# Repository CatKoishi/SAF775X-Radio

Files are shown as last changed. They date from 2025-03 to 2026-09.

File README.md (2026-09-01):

<!-- markdownlint-disable MD026 MD028 MD033 MD041 -->

<div align="center">
  <a href="https://github.com/CatKoishi" target="_blank">
    
  </a>

<h1><ruby>SAF775X Radio<rp>(</rp><rt>DIRANA3 收音机</rt><rp>)</ruby></h1>

</div>

主图 收音机实物图

## 📖 简介

基于恩智浦 Dirana3 系列的多波段收音机，具体型号为 SAF775X，支持双天线接收，可启用多种高级收音算法，由于使用的是演示密钥，所以开机3小时后会自动复位

此密钥不涉及对 SAF775X 芯片的破解，没有商用价值，与 NXP 的企业权益无冲突，演示密钥与部分程序来源于[rayc345/WTCRC775X](https://github.com/rayc345/WTCRC775X)

#### 🔗 项目链接

 ➡️ [软件开源 GitHub](https://github.com/CatKoishi/SAF775X-Radio)

 ➡️ [硬件开源 OSHWHub](https://oshwhub.com/imhhh/saf775x-radio)

## 📦 功能

略，请看视频（没录）

## 📦 ToDo

- [ ] 收音动态高切调节
- [ ] 音频静态/动态响度
- [ ] 音频正弦波/噪声发生器UI
- [ ] ALE 自动响度均衡
- [x] UltraBass 自适应虚拟低音
- [ ] 音频滤波器组驱动与UI
- [x] 扬声器启用自动单声道
- [ ] 主界面EQ/Tone
- [ ] 低功耗与关机
- [ ] 针对AM噪声的pEQ
- [ ] 利用通用滤波器，延迟线的伪立体声

## 固件下载/更新

### 下载

方法 1:

- 将收音机通过 USB 连接到电脑（需安装CH340驱动）
- 打开收音机电源开关到耳机方向
- **保持短接** "J401" 的同时短按复位键
- 通过 `GD32 All In One Programmer`（GD官网提供）使用串口下载

方法 2:

- 使用调试器（DAP-Link，GD-Link等）下载

### 更新

- 将收音机通过 USB 连接到电脑（需安装CH340驱动）
- 进入菜单，导航到 `Device`-`Firmware Update` 按下 OK 键
- 长按 OK 键直到屏幕内容消失
- 通过 `GD32 All In One Programmer`（GD官网提供）使用串口下载

---

### Download

Method 1: 

- Connect the radio to your PC with functional USB cable(CH340 Driver Required)
- Turn on the power switch
- **Keep** Jumper "J401" shorted and press RST button
- Use `GD32 All In One Programmer`(Provided by GigaDevice) to download

Method 2:

- Use Debugger(DAP-Link, GD-Link, etc.) to download directly

### Update

- Connect the radio to your PC with functional USB cable(CH340 Driver Required)
- Navigate to `Device`-`Firmware Update` and press OK button
- Long press OK button and wait for screen turn off
- Use `GD32 All In One Programmer`(Provided by GigaDevice) to download

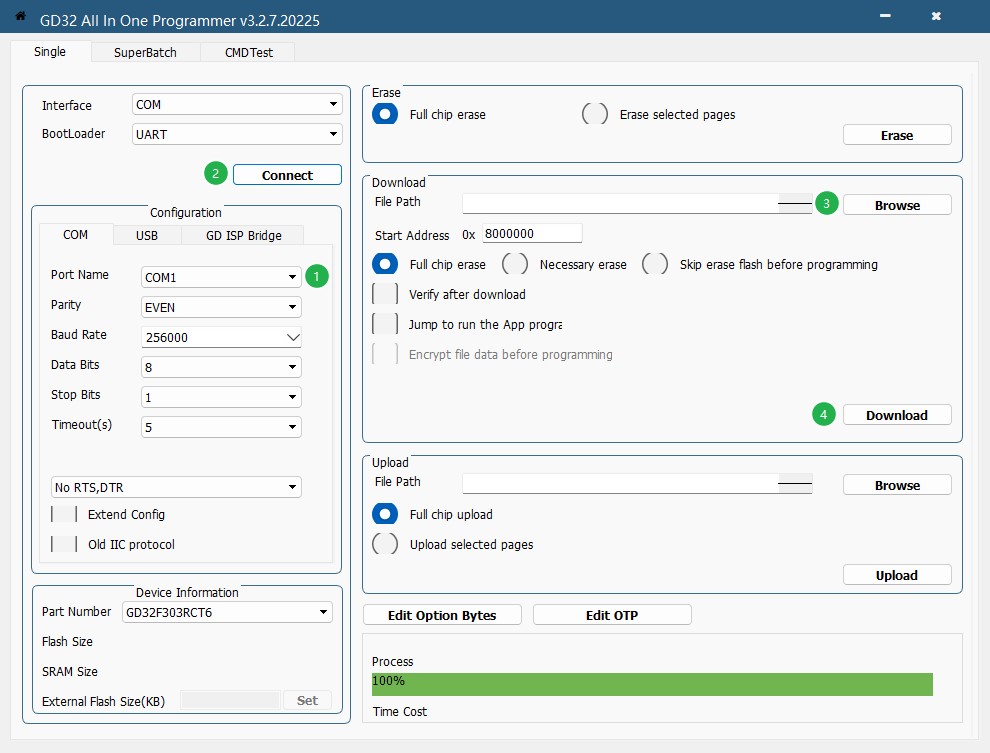
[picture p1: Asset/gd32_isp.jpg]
ISP GD32 All In One Programmer流程


---

## 📝 更新记录

### 20260831-2.10

- 增加音频采样率切换

### 20260829-2.9

- 优化菜单位置
- 支持交换左右编码器功能

### 20260605-2.8.1

- 修复多处无关设置
- 修复结构体更新后 flash 没有同步更新的问题
- 更新 README 固件下载/更新方法
### 20260831-2.9

- 增加 44.1 kHz 与 48 kHz 采样率切换

### 20260527-2.8

- 新增 Coax Output 与 Host I2S0 Out 开关
- 启用 Coax Output 或 Host I2S0 Out 时自动关闭 AMP 电源，避免喇叭继续输出
- 优化同轴/Host I2S0 输出切换时的喇叭输出控制
- 调整存台上限：LW 20 台，MW 50 台，FM 150 台，SW 200 台
- 修复 100 台以上存台时的索引与主界面显示问题
- 修复 ATS Threshold 设置无法保存的问题

### 20260519-2.7

- 增加电台删除功能 [设置-Search-Manage Memory]

### 20260417-2.6

- 修复错误的 SFUD 擦除参数
- CRC 相同的实时信息不会写入 Flash

### 20260101-2.5

- 修复设置保存在某些情况下的错误
- 修复错误的静音设置
- 修复启动过程中某些配置未设置

### 20251121-2.4

- 将 FlashDB 更换为 LittleFS, 理论上储存更加稳健

### 20250707-2.3.1

- 开机按住左编码器会强制初始化设置
- 限制对比度调节范围

### 20250408-2.3

- Flash 驱动改为 SFUD，理论上兼容所有支持 JEDEC 标准的 Flash (容量 > 2MByte)
- 修复某些情况下 Device 下的设置不保存的问题

### 20250321-2.2.1

- 设置版本不匹配时重置数据库，减小报错

### 20250320-2.2

- 增加 RDS RadioText 显示
- 非 EmiFree 模式下存台信息由 CH.05 改为 CH.05/14
- 将存台序号最小值改为 01
- 修复在非 EmiFree 模式下 RDS PI 码侵占存台序号的问题
- 修复进退菜单后主界面的 RDS PI/PS 信息丢失
- 修复错误读取版本信息

### 20250311-2.1

- FMSI 立体声等级可调
- 使用扬声器时可设置自动输出单声道（提高信噪比）

### 20250308-2.0

- FM切换频率无静音
- 所有设置使用FlashDB存储，支持Flash磨损均衡
- 无操作1分钟后存储实时信息
- 增加主菜单图标

<details>
<summary>历史记录（点击展开）</summary>

### 20240802-1.7a

- 超频SPI通讯速率到30MH

### 20240801-1.7

- 重构主界面UI
- 新增Audio目录图标
- 新增RDS PI PS信息展示

### 20240723-1.6

- 重构LCD DMA刷屏函数与GUI函数，减小屏幕通信干扰
- 修复开机屏幕不打开无限背光的Bug

### 20231105-1.5

- 增加DAC音频增益3dB
- 略微降低屏幕通信干扰
- VU表自衰减

### 20231007-1.4

- 新增About图标

### 20230924(ER)

- 修复flash排列错误

### 20230921-1.4

- 修复开机LNA不启用的Bug
- 时钟源更改为内部RC振荡器
- 版本标记修改
- 增加UltraBass功能（KeyCode）
- 增加GSA，VU流畅度

### 20230913-1.3

- 修复切换波段静音解除的问题
- 修复775x复位后静音解除的问题
- 增加NoiseBlanker, SoftMute设置
- 设置带宽增加指示

### 20230912-1.2

- 修改音量线性度
- 修改音量步进
- 优化GSA,VU,RSSI延迟
- 加快VU表衰落速度

### 20230911-1.1

- 降低屏幕通信干扰

</details>

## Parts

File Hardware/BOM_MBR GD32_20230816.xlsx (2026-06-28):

主板
No. | Quantity | Comment | Designator | Footprint | Value | Manufacturer Part | Manufacturer | Supplier Part | Supplier | Device
1 | 3 | PH-2AW | BAT1,SPK1,SPK2 | CONN-TH_2P-P2.00_PH-2AW |  | PH-2AW | BOOMELE(博穆精密) | C16965 | LCSC | PH-2AW_C16965
2 | 2 | 6.8n | C1,C2 | C0603_S | 6.8n |  |  |  |  | CAP_0603
3 | 2 | 47n | C3,C5 | C0603 | 47n |  |  |  |  | CAP_0603
4 | 1 | 62p | C4 | C0603 | 62p |  |  |  |  | CAP_0603
5 | 6 | 22u | C101,C102,C104,C105,C427,C430 | C0805 | 22u |  |  |  |  | CAP_0805
6 | 15 | 1u | C107,C108,C111,C112,C213,C220,C228,C249,C254,C262,C266,C303,C304,C409,C424 | C0603_S | 1u |  |  |  |  | CAP_0603
7 | 18 | 10u | C109,C110,C113,C114,C115,C118,C119,C120,C121,C128,C129,C133,C201,C401,C404,C425,C429,C431 | C0603_S | 10u |  |  |  |  | CAP_0603
8 | 8 | 1n | C117,C205,C207,C209,C232,C234,C251,C252 | C0603_S | 1n |  |  |  |  | CAP_0603
9 | 2 | 100u | C122,C131 | CAP-SMD_L3.5-W2.8 | 100u | TAJB107K006RNJ | Kyocera AVX | C16133 | LCSC | TAJB107K006RNJ
10 | 39 | 100n | C123,C124,C132,C202,C203,C204,C206,C208,C210,C211,C212,C217,C218,C219,C221,C240,C246,C247,C250,C255,C263,C264,C265,C267,C305,C307,C313,C320,C325,C402,C403,C405,C406,C407,C408,C411,C415,C421,C428 | C0603_S | 100n |  |  |  |  | CAP_0603
11 | 1 | 220u | C126 | CAP-TH_BD6.3-P2.50-D1.0-FD | 220u | SPZ1AM221E05O00R | AISHI(艾华集团) |  | LCSC | SPZ1AM221E05O00R
12 | 4 | 4.7u | C130,C231,C321,C326 | C0603_S | 4.7u |  |  |  |  | CAP_0603
13 | 6 | 12p | C222,C223,C422,C423,C436,C437 | C0603_S | 12p |  |  |  |  | CAP_0603
14 | 3 | 470n | C224,C301,C314 | C0603_S | 470n |  |  |  |  | CAP_0603
15 | 2 | 3.3n | C225,C245 | C0603_S | 3.3n |  |  |  |  | CAP_0603
16 | 7 | 10n | C226,C227,C410,C417,C418,C419,C420 | C0603_S | 10n |  |  |  |  | CAP_0603
17 | 2 | 1.5p | C229,C241 | C0603_S | 1.5p |  |  |  |  | CAP_0603
18 | 1 | 2.2n | C230 | C0603_S | 2.2n |  |  |  |  | CAP_0603
19 | 1 | 1p | C233 | C0603_S | 1p |  |  |  |  | CAP_0603
20 | 1 | 10p | C235 | C0603_S | 10p |  |  |  |  | CAP_0603
21 | 1 | 6p | C236 | C0603_S | 6p |  |  |  |  | CAP_0603
22 | 1 | 8p | C237 | C0603_S | 8p |  |  |  |  | CAP_0603
23 | 2 | 47n | C238,C239 | C0603_S | 47n |  |  |  |  | CAP_0603
24 | 1 | 470p | C242 | C0603_S | 470p |  |  |  |  | CAP_0603
25 | 1 | 15p | C243 | C0603_S | 15p |  |  |  |  | CAP_0603
26 | 2 | 330p | C244,C253 | C0603_S | 330p |  |  |  |  | CAP_0603
27 | 1 | 220n | C248 | C0603_S | 220n |  |  |  |  | CAP_0603
28 | 3 | 22u | C302,C318,C324 | CAP-SMD_L3.2-W1.6 | 22u | CA45-A-16V-22uF-K | CEC(振华新云) |  | LCSC | CA45-A-16V-22uF-K
29 | 4 | 2.2u | C309,C312,C317,C323 | C0603_S | 2.2u |  |  |  |  | CAP_0603
30 | 2 | 56p | C433,C434 | C0603 | 56p |  |  |  |  | CAP_0603
31 | 1 | 20p | C435 | C0603 | 20p |  |  |  |  | CAP_0603
32 | 1 | PJ-3062-HD-G | CN1 | AUDIO-TH_PJ-3062-HD-G |  | PJ-3062-HD-G | XKB Connectivity(中国星坤) | C431042 | LCSC | PJ-3062-HD-G
33 | 1 | SMF6.0CA | D101 | SOD-123FL_L2.8-W1.8-LS3.7-BI |  | SMF6.0CA | Slkor(萨科微) | C920180 | LCSC | SMF6.0CA_C920180
34 | 1 | S3MB | D102 | SMB_L4.6-W3.6-LS5.3-RD |  | S3MB | MDD | C47524 | LCSC | S3MB_C47524
35 | 2 | bf563e83ec7f4ca1b05c8bcd0d4c01ab | D201,D202 | SOD523 |  |  |  |  |  | BA891
36 | 1 | SD103AWS | D403 | SOD-323_L1.8-W1.3-LS2.5-RD |  | SD103AWS | Hottech(合科泰) | C181207 | LCSC | SD103AWS
37 | 2 | CBW322513U221T | FB1,FB2 | IND-SMD_L3.2-W2.5_L3225 |  | CBW322513U221T | FH(风华) | C394512 | LCSC | CBW322513U221T
38 | 1 | AFA01-S16FCA-00 | FPC403 | FPC-SMD_P1.00-16P_FGS-XJ-H2.0 |  | AFA01-S16FCA-00 | JS(钜硕电子) | C262758 | LCSC | AFA01-S16FCA-00
39 | 2 | HDR-M_2.54_1x2P | J401,MW_ANT1 | HDR-TH_2P-P2.54-V-M-1 |  |  |  | C124375 |  | HDR-M_2.54_1x2P
40 | 2 | 150nH | L1,L4 | L0603 | 150nH |  |  |  |  | L_0603
41 | 2 | 82nH | L2,L3 | L0603 | 82nH |  |  |  |  | L_0603
42 | 1 | 51nH | L6 | L0603 | 51nH |  |  |  |  | L_0603
43 | 1 | 2.2uH | L101 | IND-SMD_L7.4-W6.6_1 |  | MS0630-2R2M | COILMX | C380175 | LCSC | 2.2uH
44 | 6 | BLM18AG601SN1D | L201,L202,L203,L206,L212,L401 | L0603 |  | BLM18AG601SN1D | muRata(村田) | C19330 | LCSC | BLM18AG601SN1D
45 | 2 | 47uH | L204,L205 | L1210 | 47uH | LQH32MN470J23L | muRata(村田) | C113077 | LCSC | LQH32MN470J23L
46 | 1 | 880nH | L207 | L1206 | 880nH | LQH31HNR88J03L | muRata(村田) | C417125 | LCSC | LQH31HNR88J03L
47 | 1 | 3.3uH | L208 | IND-SMD_L2.9-W2.5 | 3.3uH | AISC-1008F-3R3G-T | ABRACON | C187024 | LCSC | AISC-1008F-3R3G-T
48 | 1 | 290nH | L209 | L1206 | 290nH | LQH31HNR29K03L | muRata(村田) | C337900 | LCSC | LQH31HNR29K03L
49 | 1 | 270nH | L210 | IND-SMD_L2.9-W2.8 | 270nH | AISC-1008-R27G-T | ABRACON | C186997 | LCSC | AISC-1008-R27G-T
50 | 1 | 2.2uH | L402 | IND-SMD_L2.5-W2.0 | 2.2uH | 252012CDMCDDS-2R2MC | Sumida(胜美达) | C351245 | LCSC | 252012CDMCDDS-2R2MC
51 | 1 | LED-0603_R | LED101 | LED0603_RED |  | 19-217/R6C-AL1M2VY/3T | EVERLIGHT(台湾亿光) | C72044 | LCSC | LED-0603_R_LED0603_RED(1)
52 | 1 | SK-12E12-G5 | PWR_SW1 | SW-TH_SK-12E12-G5 |  | SK-12E12-G5 | 韩国韩荣 | C136720 | LCSC | SK-12E12-G5
53 | 1 | AP60P20Q | Q101 | DFN-8_L3.3-W3.3-P0.65-BL |  | AP60P20Q | ALLPOWER(铨力) | C2828591 | LCSC | AP60P20Q
54 | 2 | WST2333 | Q102,Q105 | SOT-23-3_L2.9-W1.3-P1.90-LS2.4-BR_1 |  | WST2333 | WINSOK微硕 | C377859 | LCSC | WST2333
55 | 2 | WNM2021 | Q103,Q104 | SOT-323-3_L2.0-W1.3-P1.30-LS2.1-BR |  | WNM2021 | TECH PUBLIC(台舟) | C2940608 | LCSC | WNM2021
56 | 1 | BC847B,215 | Q201 | SOT-23-3_L2.9-W1.3-P1.90-LS2.4-BR |  | BC847B,215 | Nexperia(安世) | C57668 | LCSC | BC847B,215
57 | 1 | 0.5 | R101 | R0603 | 0.5 |  |  |  |  | Res_0603
58 | 7 | 51K | R102,R113,R117,R314,R322,R324,R419 | R0603 | 51K |  |  |  |  | Res_0603
59 | 3 | 1K | R103,R104,R121 | R0603 | 1K |  |  |  |  | Res_0603
60 | 2 | 5.1K | R105,R106 | R0603 | 5.1K |  |  |  |  | Res_0603
61 | 14 | 10K | R107,R110,R122,R205,R206,R401,R402,R403,R414,R416,R423,R425,R426,R428 | R0603 | 10K |  |  |  |  | Res_0603
62 | 11 | 100K | R108,R111,R114,R115,R118,R119,R123,R318,R420,R429,R430 | R0603 | 100K |  |  |  |  | Res_0603
63 | 1 | 10 | R109 | R0603 | 10 |  |  |  |  | Res_0603
64 | 2 | 147K | R112,R417 | R0603 | 147K |  |  |  |  | Res_0603
65 | 8 | 21K | R116,R217,R301,R302,R303,R313,R316,R317 | R0603 | 21K |  |  |  |  | Res_0603
66 | 3 | 3.3K | R120,R421,R422 | R0603 | 3.3K |  |  |  |  | Res_0603
67 | 1 | 82 | R201 | R0603 | 82 |  |  |  |  | Res_0603
68 | 1 | NC | R202 | R0603 | NC |  |  |  |  | Res_0603
69 | 2 | 470K | R203,R204 | R0603 | 470K |  |  |  |  | Res_0603
70 | 2 | 22 | R207,R209 | R0603 | 22 |  |  |  |  | Res_0603
71 | 1 | 18 | R208 | R0603 | 18 |  |  |  |  | Res_0603
72 | 4 | 100 | R210,R211,R215,R424 | R0603 | 100 |  |  |  |  | Res_0603
73 | 1 | 820 | R212 | R0603 | 820 |  |  |  |  | Res_0603
74 | 3 | 1M | R213,R214,R415 | R0402 | 1M |  |  |  |  | Res_0402
75 | 1 | 2.2K | R216 | R0603 | 2.2K |  |  |  |  | Res_0603
76 | 2 | U.FL-R-SMT-1(80) | RF201,RF202 | RF-SMD_FRF05002-JSS103M |  | U.FL-R-SMT-1(80) | HRS(广濑) | C88374 | LCSC | U.FL-R-SMT-1(80)_C88374
77 | 4 | 100 | RN401,RN403,RN405,RN406 | RES-ARRAY-SMD_0603-8P-L3.2-W1.6-BL | 100 | RC-ML08W101JT | FH(风华) | C79203 | LCSC | RC-ML08W101JT
78 | 1 | TS342A2P-WZ | RST1 | SW-SMD_L4.0-W2.9-LS5.0 |  | TS342A2P-WZ | SHOU HAN(首韩) | C557591 | LCSC | TS342A2P-WZ
79 | 1 | HDR-M_2.54_1x3P | SWD1 | HDR-TH_3P-P2.54-V-M |  |  |  | C2937625 |  | HDR-M_2.54_1x3P
80 | 1 | A1313AN-0001GGH=P3 | T201 | 5CCEG |  |  |  |  |  | A1313AN-0001GGH=P3
81 | 1 | AW5026DNR | U1 | DFN-6_L1.1-W0.9-P0.40-BL |  | AW5026DNR | AWINIC(艾为) | C5125888 | LCSC | AW5026DNR
82 | 1 | IP2312U_VSET | U101 | SOP-8_L4.9-W3.9-P1.27-LS6.0-BL-EP |  | IP2312U_VSET | INJOINIC(英集芯) | C605432 | LCSC | IP2312U_VSET
83 | 2 | WL2863E33-5 | U102,U103 | SOT-23-5_L2.9-W1.6-P0.95-LS2.8-TL |  |  |  |  |  | WL2863E33-5
84 | 2 | SUL6001DRB | U104,U105 | WDFN-8L_L3.0-W3.0-P0.65-BL-EP |  | SUL6001DRB | suntek(洺太电子) | C5120336 | LCSC | SUL6001DRB
85 | 1 | SAF775X | U201 | HLQFP-176_L24.0-W24.0-P0.5-LS26.0-BL-EP |  |  |  |  |  | SAF775X
86 | 1 | M25P16-VMN6TP | U202 | SOIC-8_L4.9-W3.9-P1.27-LS6.0-BL |  | M25P16-VMN6TP | micron(镁光) | C151067 | LCSC | M25P16-VMN6TP
87 | 1 | MAX97220AETE+T | U301 | QFN-16_L3.0-W3.0-P0.50-BL-EP1.5 |  | MAX97220AETE+T | MAXIM(美信) | C2682711 | LCSC | MAX97220AETE+T
88 | 1 | CH340E | U401 | MSOP-10_L3.0-W3.0-P0.50-LS5.0-BL |  | CH340E | WCH(南京沁恒) | C99652 | LCSC | CH340E
89 | 1 | GD32F303RCT6 | U402 | LQFP-64_L10.0-W10.0-P0.50-LS12.0-BL |  | GD32F303RCT6 | GigaDevice(兆易创新) | C131443 | LCSC | GD32F303RCT6
90 | 1 | ZD25WQ16BTIGT | U403 | SOP-8_L5.0-W4.0-P1.27-LS6.0-BL |  | ZD25WQ16BTIGT | Zetta(澜智) | C969904 | LCSC | ZD25WQ16BTIGT
91 | 1 | 74LVC1G17W5-7 | U404 | SOT-25-5_L3.0-W1.8-P0.95-LS3.0-BL |  | 74LVC1G17W5-7 | DIODES(美台) | C151394 | LCSC | 74LVC1G17W5-7
92 | 1 | TPS62290DRVR | U407 | WSON-6_L2.0-W2.0-P0.65-TL-EP |  | TPS62290DRVR | TI(德州仪器) | C129315 | LCSC | TPS62290DRVR
93 | 2 | AD4150B | U408,U409 | MSOP-8_L3.0-W3.0-P0.65-LS4.9-BL |  | AD4150B | IDCHIP(英锐芯) | C5125078 | LCSC | AD4150B
94 | 1 | TYPE-C-31-M-12 | USBC101 | USB-C_SMD-TYPE-C-31-M-12 |  | TYPE-C-31-M-12 | 韩国韩荣 | C165948 | LCSC | TYPE-C-31-M-12
95 | 1 | 55.46667MHz | X201 | OSC-SMD_4P-L3.2-W2.5-BL | 55.46667MHz |  | TXC |  |  | X322512MSB4SI
96 | 1 | 8MHz | X401 | OSC-SMD_4P-L3.2-W2.5-BL | 8MHz | X32258MOB4SI | YXC(扬兴晶振) | C2682775 | LCSC | X32258MOB4SI
97 | 1 | 32.768kHz | X402 | OSC-SMD_L3.2-W1.5 | 32.768kHz | X321532768KGD2SI | YXC(扬兴晶振) | C620155 | LCSC | X321532768KGD2SI
副板
1 | 6 | 1u | C1,C2,C3,C4,C9,C10 | C0603_S | 1u |  |  |  |  | CAP_0603
2 | 1 | 100n | C5 | C0603_S | 100n |  |  |  |  | CAP_0603
3 | 1 | 4.7u | C6 | C0603_S | 4.7u |  |  |  |  | CAP_0603
4 | 1 | 470p | C7 | C0603_S | 470p |  |  |  |  | CAP_0603
5 | 1 | 10u | C8 | C0603_S | 10u |  |  |  |  | CAP_0603
6 | 1 | AFA01-S16FCA-00 | FPC1 | FPC-SMD_P1.00-16P_FGS-XJ-H2.0 |  | AFA01-S16FCA-00 | JS(钜硕电子) | C262758 | LCSC | AFA01-S16FCA-00
7 | 1 | WNM2021 | Q1 | SOT-323-3_L2.2-W1.3-P1.30-LS2.1-BR |  | WNM2021 | TECH PUBLIC(台舟) | C2940608 | LCSC | WNM2021
8 | 1 | NC | R1 | R0603 | NC |  |  |  |  | Res_0603
9 | 1 | NO | R2 | R0603 | NO |  |  |  |  | Res_0603
10 | 1 | 470K | R3 | R0603 | 470K |  |  |  |  | Res_0603
11 | 1 | 1M | R4 | R0603 | 1M |  |  |  |  | Res_0603
12 | 8 | 10K | R5,R7,R11,R16,R17,R18,R19,R20 | R0603 | 10K |  |  |  |  | Res_0603
13 | 2 | 100K | R6,R9 | R0603 | 100K |  |  |  |  | Res_0603
14 | 1 | 10 | R8 | R0603 | 10 |  |  |  |  | Res_0603
15 | 2 | 5.1K | R10,R12 | R0603 | 5.1K |  |  |  |  | Res_0603
16 | 1 | 2.2K | R13 | R0603 | 2.2K |  |  |  |  | Res_0603
17 | 2 | 1K | R14,R15 | R0603 | 1K |  |  |  |  | Res_0603
18 | 1 | 100 | R21 | R0603 | 100 |  |  |  |  | Res_0603
19 | 4 | K2-1817UQ-C4SW-01 | SW1,SW2,SW3,SW4 | KEY-SMD_2P-L6.0-W6.0-P6.00 |  | K2-1817UQ-C4SW-01 | 韩国韩荣 | C128939 | LCSC | K2-1817UQ-C4SW-01
20 | 1 | JLX25696G-968-BN | U1 | SFPC26_P0.8_W0.4_H3.0 |  |  | 晶联讯 |  |  | JLX25696G-968-BN
21 | 1 | LMV321IDBVR | U2 | SOT-23-5_L3.0-W1.7-P0.95-LS2.8-BR |  | LMV321IDBVR | TI(德州仪器) | C7972 | LCSC | LMV321IDBVR_C7972
22 | 1 | ME6217C33M5G | U3 | SOT-23-5_L3.0-W1.7-P0.95-LS2.8-BR |  | ME6217C33M5G | MICRONE(南京微盟) | C427602 | LCSC | ME6217C33M5G
23 | 2 | EC11B2AIPKF | U4,U5 | SW-TH_EC11A |  |  |  |  |  | EC11B2AIPKF
其它
 | 2 | SMA母头内孔，焊接型 | 尚深旗舰店，SMA-KY
 | 2 | RG1.13同轴线，1代IPEX转焊接 | 10cm
 | 1 | 扬声器5038 | 福声
 | 若干 | M2螺丝6mm（沉头）
 | 若干 | M2螺丝10mm（圆头带垫5mm）
 | 若干 | M2热熔螺母3.5*4mm
 | 1 | 10*（90~100）mm磁棒天线，470uH
 | 1 | 锂电池，带保护板 | 136074/136077
 | 2 | 编码器键帽25*10mm
 | 1 | FPC排线（不同面）16P，1mm，长50~100mm
 | 2 | 塑料脚垫32*6*2

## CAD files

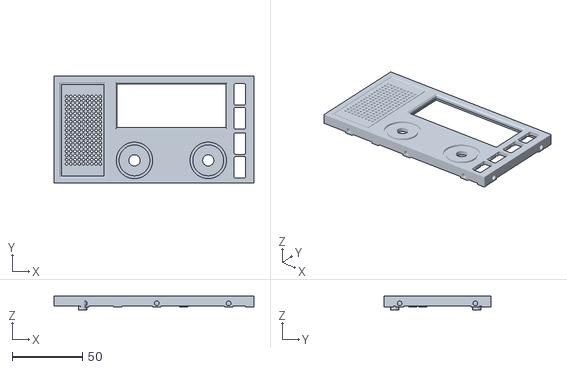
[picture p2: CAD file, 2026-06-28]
Hardware/3D Print/SAF775X Receiver Top.stl
142.6 x 76.0 x 10.0

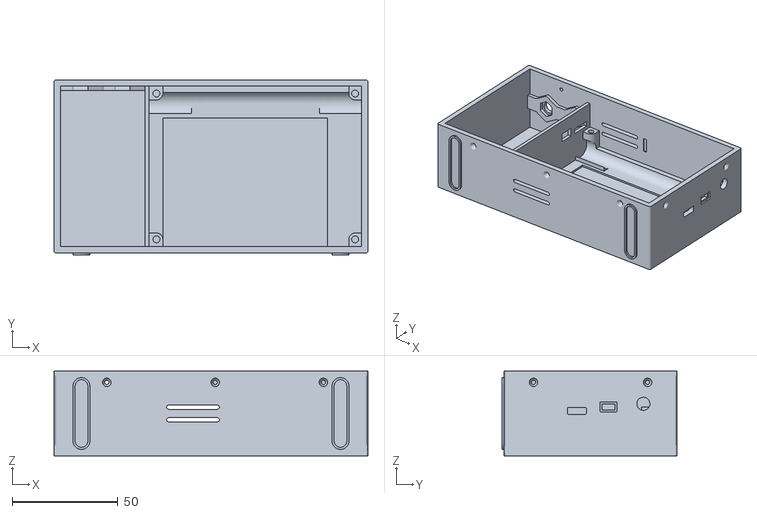
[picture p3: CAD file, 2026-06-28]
Hardware/3D Print/SAF775X Receiver Bottom.stl
148.6 x 83.0 x 40.0

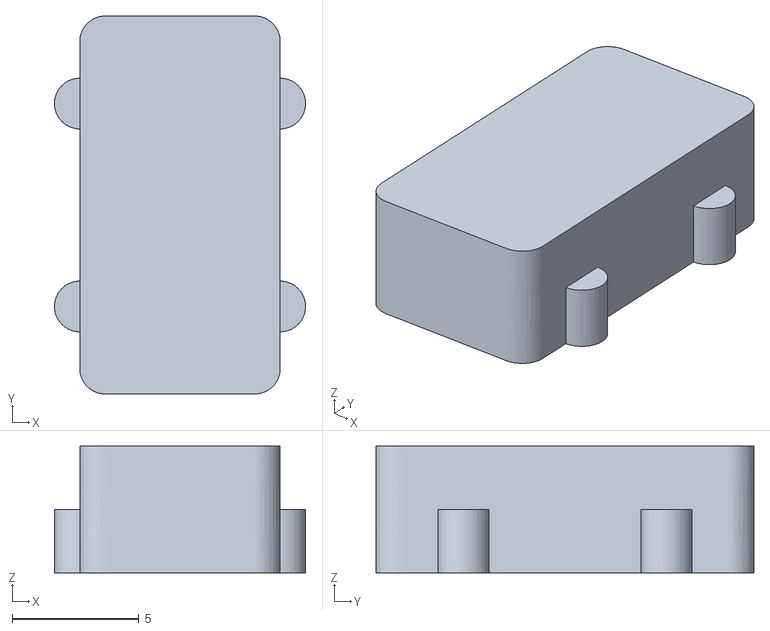
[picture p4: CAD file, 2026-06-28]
Hardware/3D Print/SAF775X Receiver Key.stl
9.90 x 14.9 x 5.00

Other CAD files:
Hardware/3D Print/SAF775X Receiver.dwg
Hardware/3D Print/SAF775X Receiver Bottom.3dm
Hardware/3D Print/SAF775X Receiver Key.3dm
Hardware/3D Print/SAF775X Receiver Top.3dm
Hardware/3D Print/SAF775X Receiver Top_ferrite.3dm

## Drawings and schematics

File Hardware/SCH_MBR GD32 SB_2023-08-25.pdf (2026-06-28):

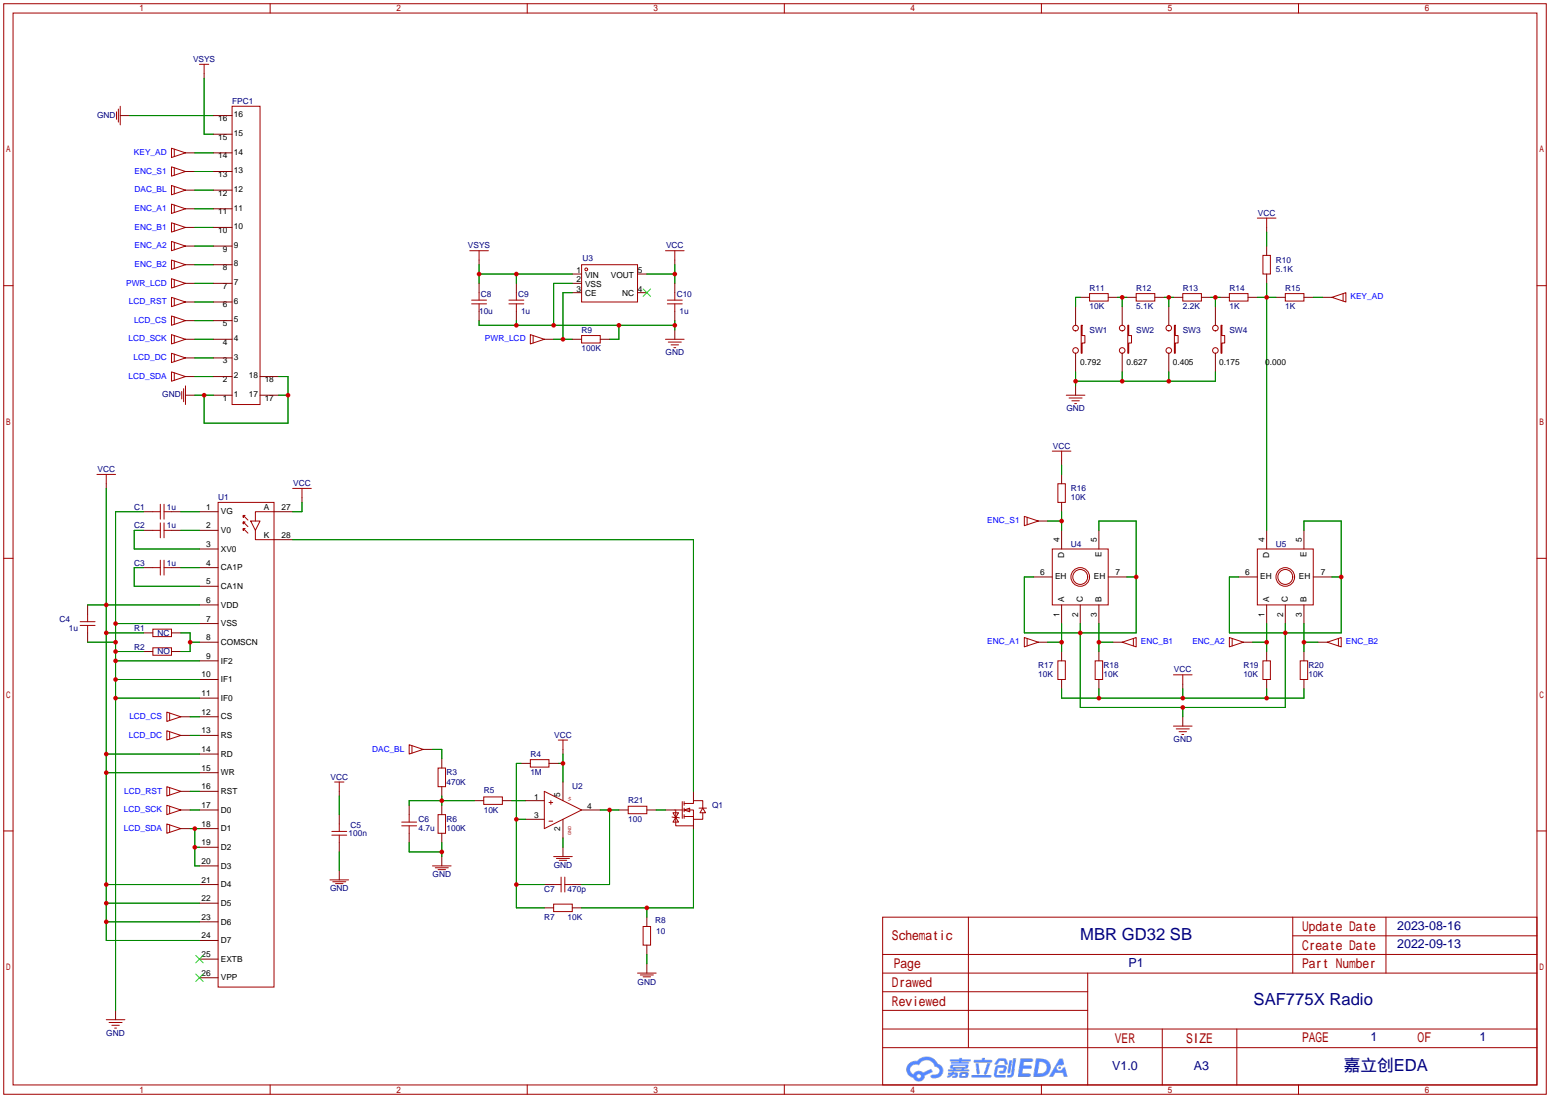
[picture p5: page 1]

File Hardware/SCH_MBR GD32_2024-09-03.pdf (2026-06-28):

# USB TYPE-C

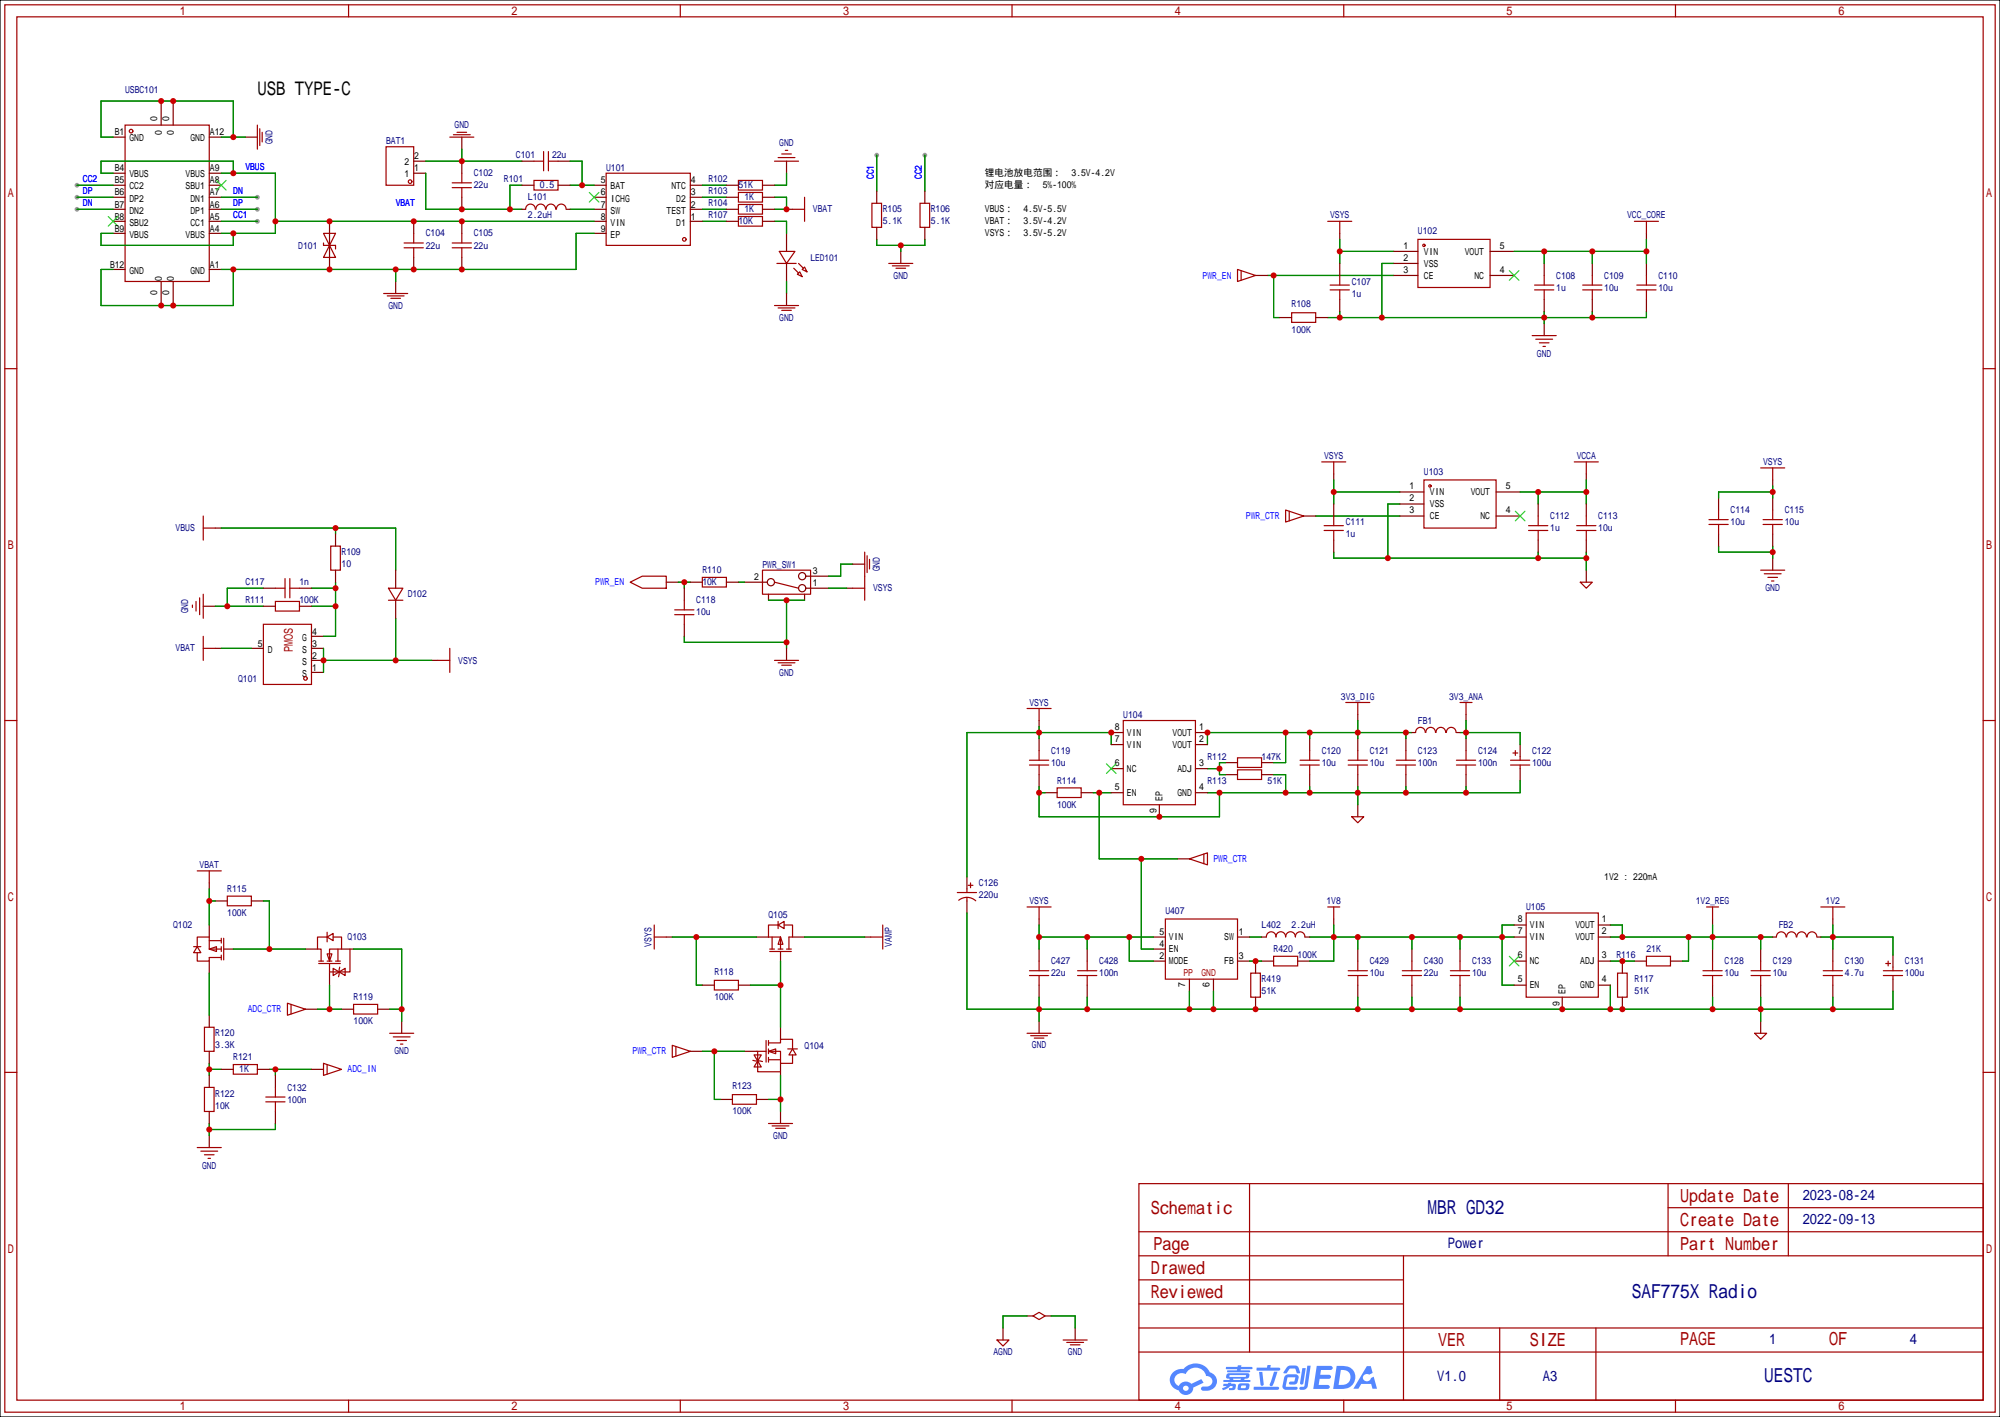
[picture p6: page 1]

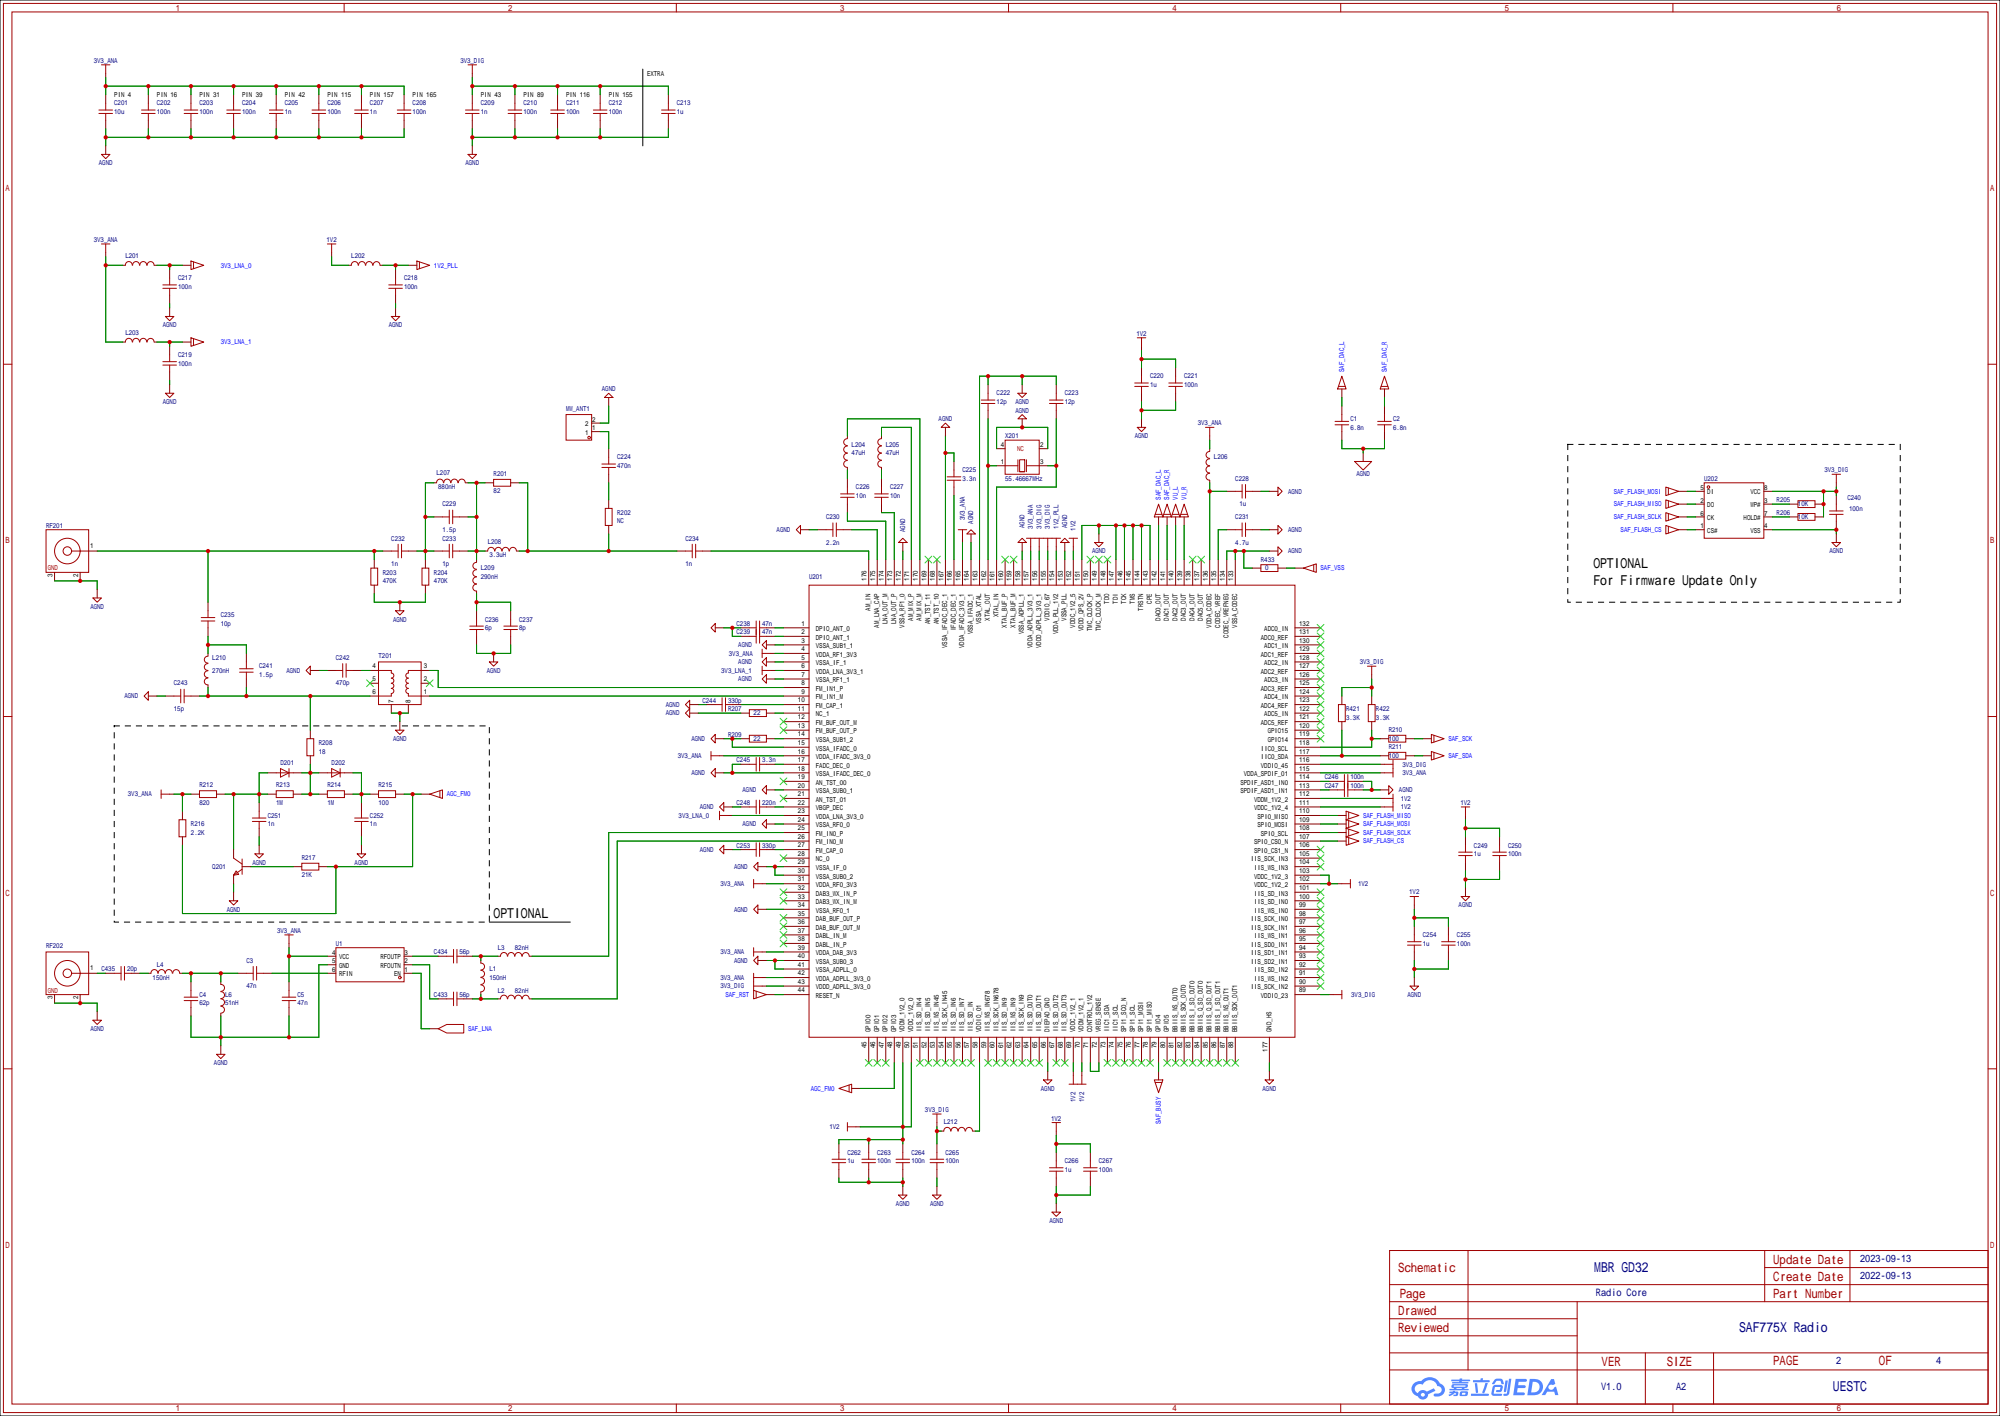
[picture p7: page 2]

OPTIONAL
For Firmware Update Only

# --将耳机插入DET输入MCU --MCU增加两个SHDN控制SPA和HPA的使能

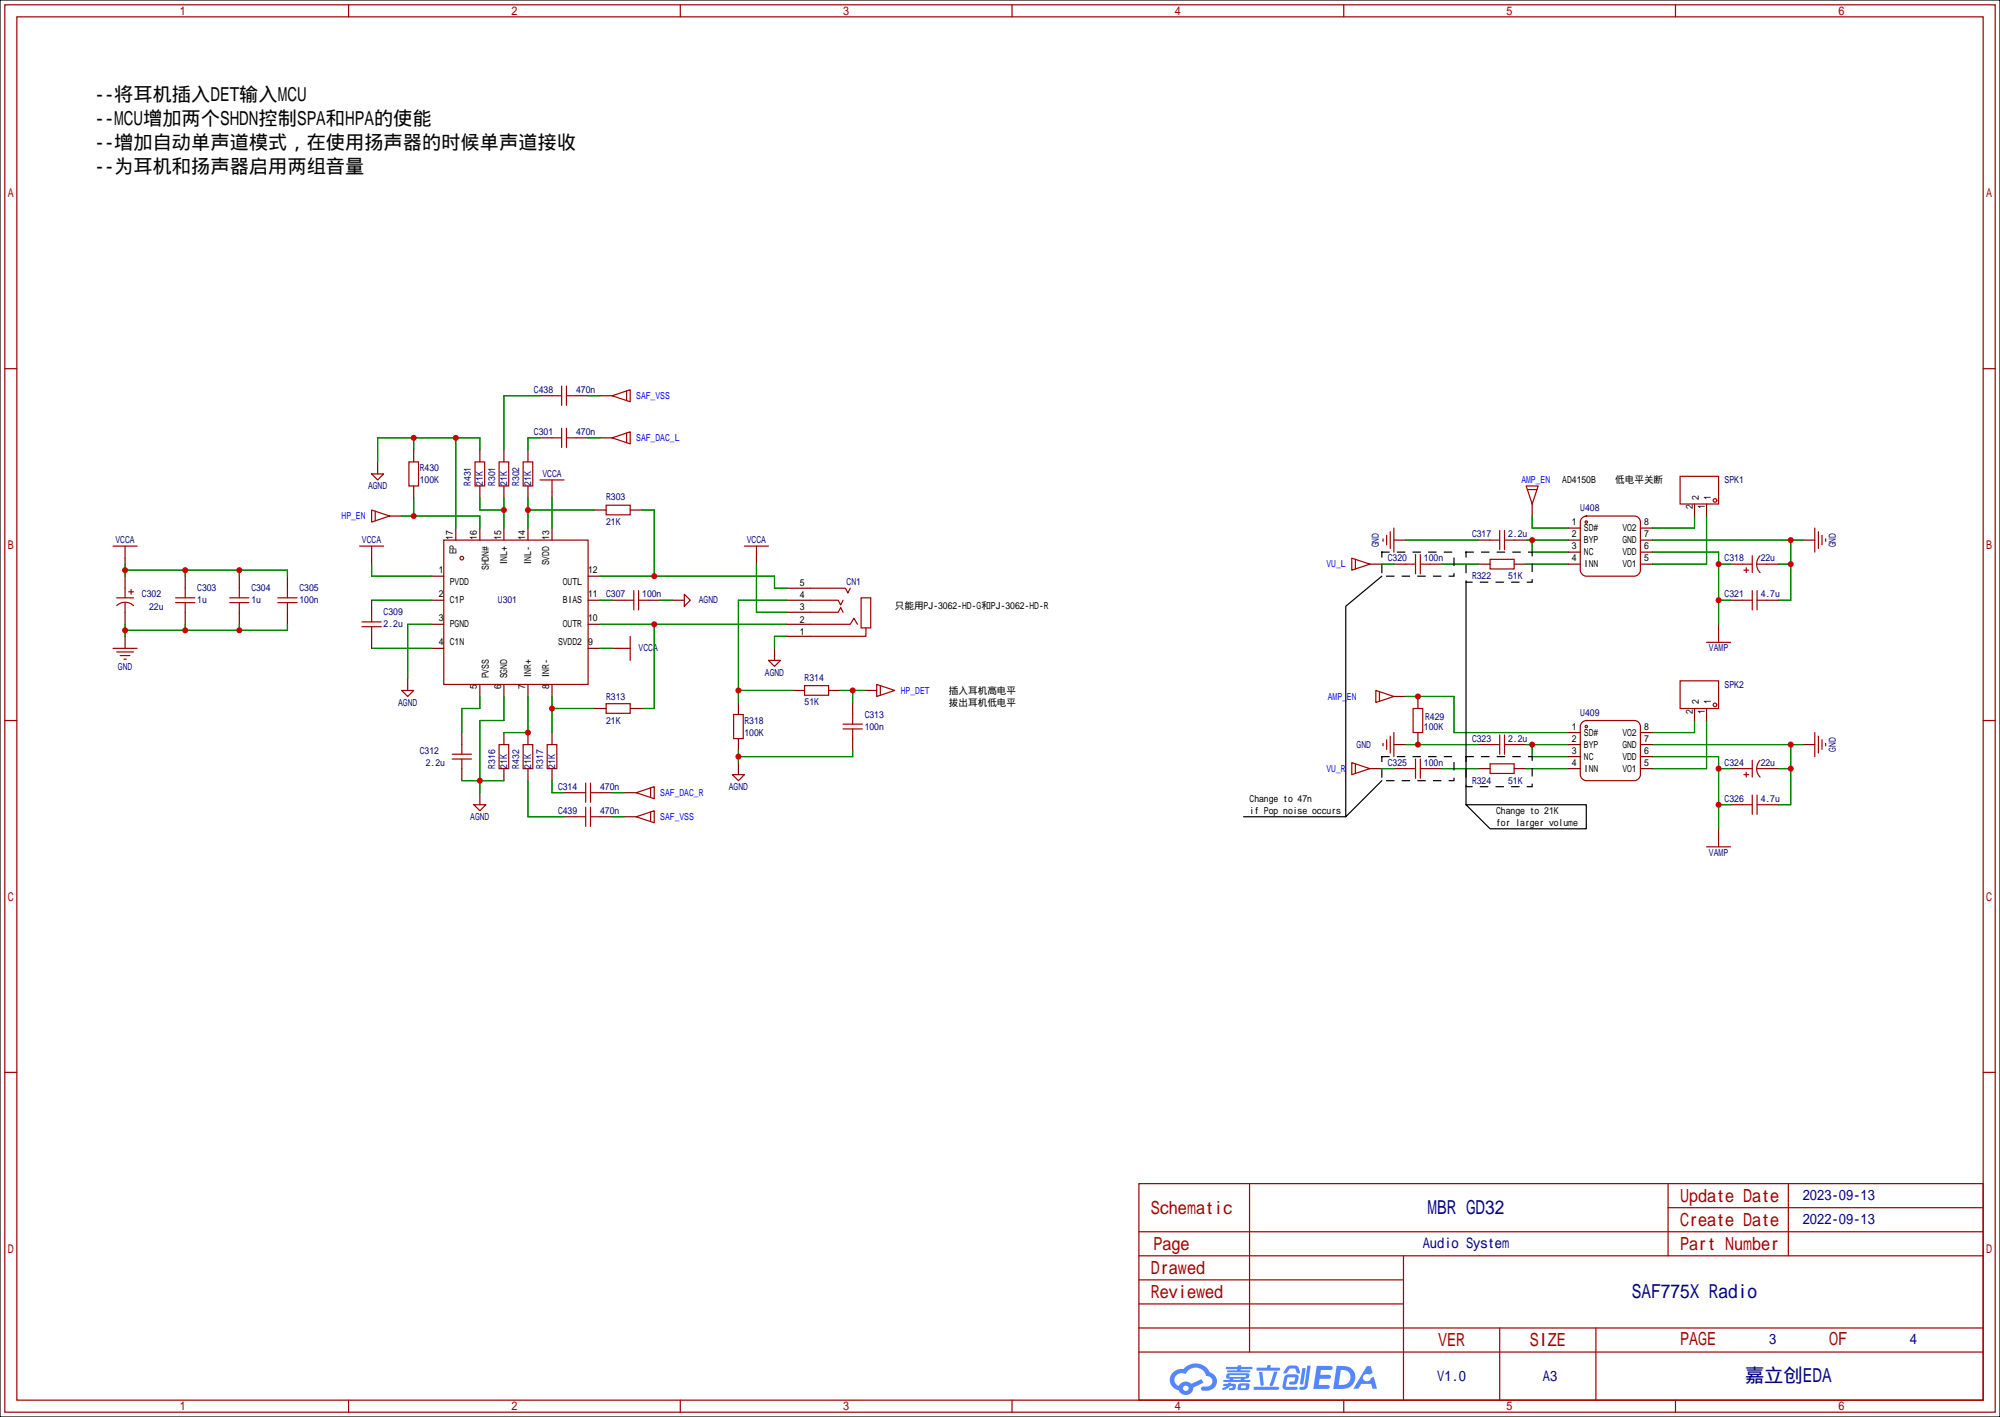
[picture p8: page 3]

只能用PJ-3062-HD-G和PJ-3062-HD-R

Change to 47n
if Pop noise occurs

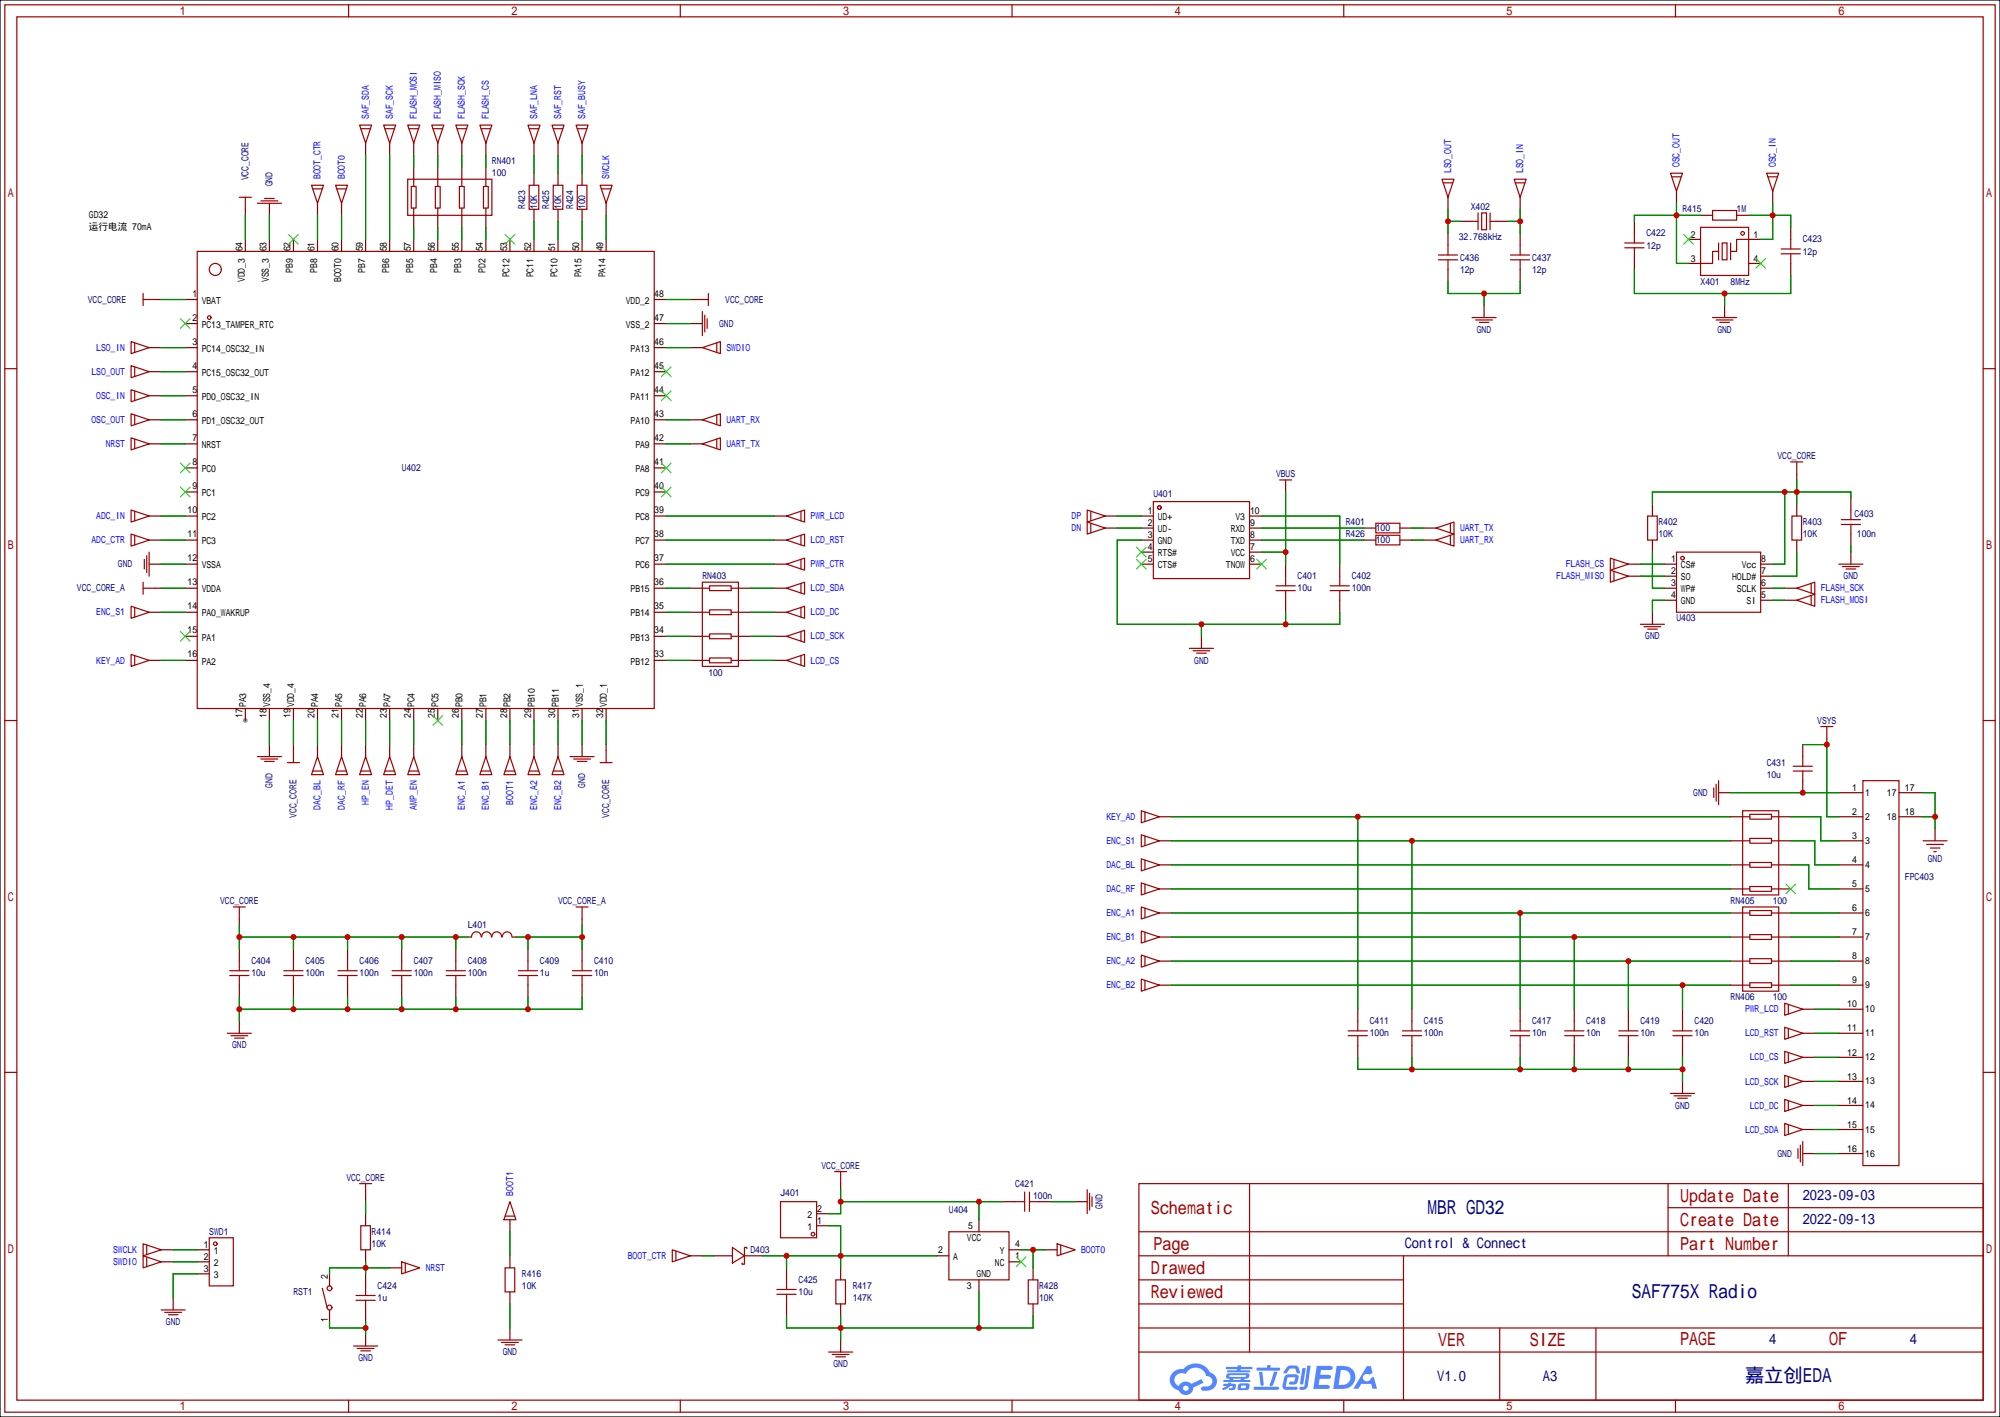
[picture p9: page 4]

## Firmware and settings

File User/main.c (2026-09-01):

#include "main.h"
#include "gd32f30x.h"
#include "systick.h"

#include <stdio.h>
#include <math.h>
#include <string.h>

#include "init.h"
#include "SAF775X.h"
#include "lcd.h"
#include "ui.h"
#include "func.h"

#include "Dirana3BasicDSP.h"

#include "lfs.h"
#include "lfs_port.h"
#include "sfud.h"

#define KEY_MENU    0
#define KEY_UP      1
#define KEY_DOWN    2
#define KEY_OK      3
#define KEY_LENC    4
#define KEY_RENC    5

#define KEY_NUM     6

#define KEY_FREE    0
#define KEY_PRESS   1
#define KEY_LP      2

/**********************************Key & ENC***********************************/

volatile uint8_t lastA1 = 1;
volatile uint8_t lastA2 = 1;
volatile uint8_t nowA1 = 1;
volatile uint8_t nowA2 = 1;

volatile uint8_t lastDET = 0;
volatile uint8_t nowDET = 0;

volatile int8_t lcode = 0;
volatile int8_t rcode = 0;

volatile int8_t* linkLcode = &lcode;
volatile int8_t* linkRcode = &rcode;

volatile uint8_t keyValue[KEY_NUM];

/*************************************Configs**********************************/

uint32_t bootCount = 0;     // 开机次数
uint32_t accBootTime = 0;   // 累计运行时间(s)

struct Dirana3Radio sTuner;

struct basicControl sAudioBasic;
struct toneControl sAudioTone;
struct graphicEQ sAudioEQ;
struct filterSystem sAudioFilter;
struct keyFunc sAudioKeyFunc;

struct lfsAudioCfg {
  struct basicControl basic;
  struct toneControl tone;
  struct graphicEQ geq;
  struct filterSystem filter;
  struct keyFunc keyf;
};

struct device sDevice = {
  .bAutoMono=true,
  .bCoaxEnable=false,
  .bI2SOutEnable=false,
  .nAudioSampleRate=AUDIO_SAMPLE_RATE_44K1,
  .bSoftReboot=true,
  .sInfo.pid[0]=18,  // flash arrange
  .sInfo.pid[1]=2,  // version
  .sInfo.pid[2]=10,  // subversion
  .sInfo.pid[3]=20260831
};

lfs_t lfs;

/************************************Var***************************************/

// DAV,GSA[0,8],VU
volatile uint8_t nGsaVal[10] = {0};
volatile uint32_t nQPeakDet;

struct RDSBuffer sRDSBuffer;
struct RDSData sRDSData;

uint32_t cfg_crc = 0;

/************************************Indicator*********************************/

volatile bool bIIC_BUSY = false;
volatile bool bMenu = false;
volatile bool bMenuLCD = false;
volatile bool bFlagRFS = false;
volatile bool bFlagGSA = false;
volatile bool bFlagRDS = false;

volatile bool bFlagReBoot = false;

volatile bool bSeek = false;

volatile bool bFilterSel = false;  //是否设置带宽

volatile int nSyncTimer = 600;
volatile bool bFlagSync = false;

volatile int nRebootTimer = 10500;

/************************************Channel***********************************/

CHANNEL nChannel[NUM_BANDS] = {
//  MaxNum,  Num, Index, Freq
  { CHS_FM,  0,   0,     {0} },
  { CHS_LW,  0,   0,     {0} },
  { CHS_MW,  0,   0,     {0} },
  { CHS_SW,  0,   0,     {0} },
};

/************************************ Flash **********************************/

char bandDbName[NUM_BANDS][7] = {"bandFm", "bandLw", "bandMw", "bandSw"};

// cfgDevice 依次保存版本、单声道、软重启、同轴、I2S、编码器交换和采样率。
#define DEVICE_CFG_WORDS 7

static bool writeConfigFile(const char *path, const void *data, lfs_size_t size)
{
  lfs_file_t file;
  lfs_ssize_t writeLen;
  int closeErr;

  if(lfs_file_open(&lfs, &file, path, LFS_O_WRONLY | LFS_O_CREAT | LFS_O_TRUNC) != 0) {
    printf("[NVM/ERR] Failed to open \"%s\" file for write.\n", path);
    return false;
  }

  writeLen = lfs_file_write(&lfs, &file, data, size);
  closeErr = lfs_file_close(&lfs, &file);

  if(writeLen != (lfs_ssize_t)size) {
    printf("[NVM/ERR] Failed to write \"%s\" file (%d/%d).\n", path, (int)writeLen, (int)size);
    return false;
  }
  if(closeErr != 0) {
    printf("[NVM/ERR] Failed to close \"%s\" file (%d).\n", path, closeErr);
    return false;
  }

  return true;
}

static lfs_ssize_t readConfigFile(const char *path, void *data, lfs_size_t size)
{
  lfs_file_t file;
  lfs_ssize_t readLen;
  int closeErr;

  if(lfs_file_open(&lfs, &file, path, LFS_O_RDONLY) != 0) {
    printf("[NVM/ERR] Failed to open \"%s\" file.\n", path);
    return -1;
  }

  readLen = lfs_file_read(&lfs, &file, data, size);
  closeErr = lfs_file_close(&lfs, &file);

  if(readLen < 0) {
    printf("[NVM/ERR] Failed to read \"%s\" file (%d).\n", path, (int)readLen);
  } else if(closeErr != 0) {
    printf("[NVM/ERR] Failed to close \"%s\" file (%d).\n", path, closeErr);
  }

  return readLen;
}

/**
 * @brief 保存指定类别的配置到 LittleFS
 * @param cfgID 配置类别
 */
void saveSettings(uint8_t cfgID)
{
  uint32_t buffer_u32[DEVICE_CFG_WORDS] = {0};
  
  if(cfgID == CFG_DEVICE || cfgID == CFG_ALL) {
    buffer_u32[0] = sDevice.sInfo.pid[0];
    buffer_u32[1] = sDevice.bAutoMono;
    buffer_u32[2] = sDevice.bSoftReboot;
    buffer_u32[3] = sDevice.bCoaxEnable;
    buffer_u32[4] = sDevice.bI2SOutEnable;
    buffer_u32[5] = sDevice.bEncoderSwap;
    buffer_u32[6] = sDevice.nAudioSampleRate;
    
    writeConfigFile("cfgDevice", buffer_u32, sizeof(buffer_u32));
  }
  
  if(cfgID == CFG_RADIO || cfgID == CFG_ALL) {
    writeConfigFile("cfgTuner", &sTuner, sizeof(sTuner));
  }
  
  if(cfgID == CFG_DISP || cfgID == CFG_ALL) {
    writeConfigFile("cfgDisplay", &sDisplay, sizeof(sDisplay));
  }
  
  if(cfgID == CFG_AUDIO || cfgID == CFG_ALL) {
    struct lfsAudioCfg t = {
      .basic = sAudioBasic,
      .filter = sAudioFilter,
      .geq = sAudioEQ,
      .tone = sAudioTone,
      .keyf = sAudioKeyFunc
    };
    writeConfigFile("cfgAudio", &t, sizeof(t));
  }
  
}

/**
 * @brief 从 LittleFS 读取指定类别的配置
 * @param cfgID 配置类别
 */
void readSettings(uint8_t cfgID)
{
  uint32_t buffer_u32[DEVICE_CFG_WORDS] = {0};
  lfs_ssize_t readLen = 0;
  
  if(cfgID == CFG_DEVICE || cfgID == CFG_ALL) {
    readLen = readConfigFile("cfgDevice", buffer_u32, sizeof(buffer_u32));
    if(readLen >= (lfs_ssize_t)(DEVICE_CFG_WORDS * sizeof(uint32_t))) {
      sDevice.bAutoMono = buffer_u32[1];
      sDevice.bSoftReboot = buffer_u32[2];
      sDevice.bCoaxEnable = buffer_u32[3];
      sDevice.bI2SOutEnable = buffer_u32[4];
      sDevice.bEncoderSwap = buffer_u32[5];
      // 采样率只允许两种硬件支持的值，异常配置统一回退到 44.1 kHz。
      sDevice.nAudioSampleRate = buffer_u32[6] <= AUDIO_SAMPLE_RATE_48K
        ? buffer_u32[6]
        : AUDIO_SAMPLE_RATE_44K1;
    }
  }
  
  if(cfgID == CFG_RADIO || cfgID == CFG_ALL) {
    struct Dirana3Radio tunerCfg = {0};
    readLen = readConfigFile("cfgTuner", &tunerCfg, sizeof(tunerCfg));
    if(readLen == (lfs_ssize_t)sizeof(tunerCfg)) {
      sTuner = tunerCfg;
      nBandStepATS[BAND_MW] = sTuner.ATS.nMWStep;
    } else if(readLen > 0) {
      printf("[NVM/WARN] Unexpected \"cfgTuner\" size: %d/%d.\n", (int)readLen, (int)sizeof(tunerCfg));
    }
  }
  
  if(cfgID == CFG_DISP || cfgID == CFG_ALL) {
    struct displayConfig displayCfg = {0};
    readLen = readConfigFile("cfgDisplay", &displayCfg, sizeof(displayCfg));
    if(readLen == (lfs_ssize_t)sizeof(displayCfg)) {
      sDisplay = displayCfg;
    } else if(readLen > 0) {
      printf("[NVM/WARN] Unexpected \"cfgDisplay\" size: %d/%d.\n", (int)readLen, (int)sizeof(displayCfg));
    }
  }
  
  if(cfgID == CFG_AUDIO || cfgID == CFG_ALL) {
    struct lfsAudioCfg t = {0};
    readLen = readConfigFile("cfgAudio", &t, sizeof(t));
    if(readLen == (lfs_ssize_t)sizeof(t)) {
      sAudioBasic = t.basic;
      sAudioTone = t.tone;
      sAudioEQ = t.geq;
      sAudioFilter = t.filter;
      sAudioKeyFunc = t.keyf;
    } else if(readLen > 0) {
      printf("[NVM/WARN] Unexpected \"cfgAudio\" size: %d/%d.\n", (int)readLen, (int)sizeof(t));
    }
  }
}

void saveChannels(uint8_t band)
{
  if(band >= NUM_BANDS)
    return;
  
  writeConfigFile(bandDbName[band], &nChannel[band], sizeof(CHANNEL));
}

void readChannels(uint8_t band)
{
  if(band >= NUM_BANDS)
    return;
  CHANNEL tmp = {0};
  lfs_ssize_t readLen = 0;
  
  readLen = readConfigFile(bandDbName[band], &tmp, sizeof(CHANNEL));
  if(readLen == (lfs_ssize_t)sizeof(CHANNEL) && tmp.chanNum <= nChannel[band].chanMax) {
    uint8_t chanMax = nChannel[band].chanMax;
    memcpy(&nChannel[band], &tmp, sizeof(CHANNEL));
    nChannel[band].chanMax = chanMax;
    if(nChannel[band].chanNum == 0) {
      nChannel[band].nowIndex = 0;
    } else {
      nChannel[band].nowIndex = inRangeInt(0, nChannel[band].chanNum-1, nChannel[band].nowIndex);
    }
  } else if(readLen > 0) {
    printf("[NVM/WARN] Unexpected \"%s\" size: %d/%d.\n", bandDbName[band], (int)readLen, (int)sizeof(CHANNEL));
  }
}

// curFreq*4, curBand, curFilter*2, curVolumn*2, curMute
void saveBasicPara(void) {
  uint16_t bSet[10] = {0};
  
  uint32_t tmp = 0;
  
  bSet[0] = sTuner.Radio.nBandMode;
  bSet[1] = sTuner.Radio.nBandFreq[0];
  bSet[2] = sTuner.Radio.nBandFreq[1];
  bSet[3] = sTuner.Radio.nBandFreq[2];
  bSet[4] = sTuner.Radio.nBandFreq[3];
  bSet[5] = sTuner.Config.nBandFilter[0];
  bSet[6] = sTuner.Config.nBandFilter[1];
  bSet[7] = sTuner.Audio.nVolume[0];
  bSet[8] = sTuner.Audio.nVolume[1];
  bSet[9] = sTuner.Audio.bMuted;
  
  crc_data_register_reset();
  tmp = crc_block_data_calculate((uint32_t*)bSet, sizeof(bSet)/4);
  
  if(tmp != cfg_crc) {
    cfg_crc = tmp;
    writeConfigFile("basicPara", &bSet, sizeof(bSet));
  }
  
}

void readBasicPara(void) {
  uint16_t bSet[10] = {0};
  lfs_ssize_t readLen = 0;
  
  readLen = readConfigFile("basicPara", &bSet, sizeof(bSet));
  if(readLen == (lfs_ssize_t)sizeof(bSet)) {
    crc_data_register_reset();
    cfg_crc = crc_block_data_calculate((uint32_t*)bSet, sizeof(bSet)/4);
    
    sTuner.Radio.nBandMode       = bSet[0];
    sTuner.Radio.nBandFreq[0]    = bSet[1];
    sTuner.Radio.nBandFreq[1]    = bSet[2];
    sTuner.Radio.nBandFreq[2]    = bSet[3];
    sTuner.Radio.nBandFreq[3]    = bSet[4];
    sTuner.Config.nBandFilter[0] = bSet[5];
    sTuner.Config.nBandFilter[1] = bSet[6];
    sTuner.Audio.nVolume[0]      = bSet[7];
    sTuner.Audio.nVolume[1]      = bSet[8];
    sTuner.Audio.bMuted          = bSet[9];
    sTuner.Radio.nRFMode = nBandRFMode[sTuner.Radio.nBandMode];
  } else if(readLen > 0) {
    printf("[NVM/WARN] Unexpected \"basicPara\" size: %d/%d.\n", (int)readLen, (int)sizeof(bSet));
  }
}

/************************************Function*********************************/

void flushKey(void)
{
  for(uint8_t i = 0; i < KEY_NUM; i++)
    keyValue[i] = 0;
}

/**
 * @brief 根据配置绑定左右编码器的旋转与按键输入
 */
void SwapEncoder(void)
{
  if(sDevice.bEncoderSwap)
  {
    linkLcode = &rcode;
    linkRcode = &lcode;
  } else {
    linkLcode = &lcode;
    linkRcode = &rcode;
  }
}

void AdjustVolume(int8_t dir)
{
  int8_t vol = sTuner.Audio.nVolume[sTuner.Audio.index];
  
  vol = inRangeInt(MIN_VOL, MAX_VOL, vol+dir*2);
  
  SetVolume(vol);
}

void AdjustFreq(int8_t dir)
{
  uint16_t f;
  f = sTuner.Radio.nBandFreq[sTuner.Radio.nBandMode] + dir * nBandStep[sTuner.Radio.nBandMode][sTuner.Radio.nFreqStep[sTuner.Radio.nBandMode]];
  
  f = inRangeInt(nBandFMin[sTuner.Radio.nBandMode], nBandFMax[sTuner.Radio.nBandMode], f);
  
  if(sTuner.Radio.nRFMode == RFMODE_FM) {
    TuneFreq(f, Jump);
  } else {
    TuneFreq(f, Preset);
  }
  
  
  RDS_Refresh();
}

void GoFreq(uint16_t freq) {
  TuneFreq(freq, (sTuner.Radio.nBandMode == BAND_FM)? Jump : Preset);
}

void AdjustFilter(int8_t dir)
{
  int8_t index = sTuner.Config.nBandFilter[sTuner.Radio.nRFMode];
  
  index += dir;
  index = inRangeInt(0,NUM_FILTERS-1,index);
  
  SetFilter(index);
}

void AdjustAGC(int8_t dir)
{
  int8_t index = sTuner.Config.nBandAGC[sTuner.Radio.nRFMode];
  
  index += dir;
  index = inRangeInt(0,3,index);
  
  SetAGC(index);
}

void VolumeHandler(void)
{
  // 右编码器旋转
  if(rcode != 0)
  {
    AdjustVolume(rcode);
    rcode = 0;
  }
  
  // 右编码器按下
  if(keyValue[KEY_RENC] != 0)
  {
    if(keyValue[KEY_RENC] == KEY_PRESS)
    {
      SetMute(!(sTuner.Audio.bMuted));
    }
    else
    {
      if(bMenu == false) // change screen
      {
        
      }
    }
    keyValue[KEY_RENC] = 0;
  }
}

static void ApplyAudioOutputByDetect(uint8_t hpDet)
{
  if(hpDet == 1)  // headphone plugin
  {
    sTuner.Audio.index = 0;
    gpio_bit_reset(GPIOC, GPIO_PIN_4);
    gpio_bit_set(GPIOA, GPIO_PIN_6);
    sTuner.Config.bForceMono = false;
  }
  else
  {
    sTuner.Audio.index = 1;
    gpio_bit_reset(GPIOA, GPIO_PIN_6);
    if(sDevice.bCoaxEnable == false && sDevice.bI2SOutEnable == false) {
      gpio_bit_set(GPIOC, GPIO_PIN_4);
      if(sDevice.bAutoMono == true)
        sTuner.Config.bForceMono = true;
      else
        sTuner.Config.bForceMono = false;
    }
    else {
      gpio_bit_reset(GPIOC, GPIO_PIN_4);
      sTuner.Config.bForceMono = false;
    }
  }

  SetRadioSignal();
}

void reFillBackLightTimer(void)
{
  sDisplay.backTimeCounter = sDisplay.backTime*10;
  nSyncTimer = 600;
}
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
int main(void)
{
  int16_t tmpArr[4] = {0};
  uint32_t buffer_u32[4] = {0};
  
  SYS_Init();
  GPIO_Init();
  
  gpio_bit_set(GPIOC, GPIO_PIN_6); // PC6 PWR_CTR -> 3V3/1V2
  gpio_bit_set(GPIOC, GPIO_PIN_8); // PC8 PWR_LCD
  delay_ms(200);
  
  Timer_Init();
  
  ADC_Init();
  DAC_Init();
  USART_Init();
  sfud_init();
  delay_ms(10);
  
  lfs_file_t file;
  int fs_err = 0;
  int discardNVM = 0;
  
  if(sfud_lfs_init() != 0) {
    printf("[SFUD/ERR] Unable to get sfud device(Get NULL)!\n");
  }
  
  fs_err =  lfs_mount(&lfs, &lfs_cfg);
  if(fs_err) {
    lfs_format(&lfs, &lfs_cfg);
    fs_err = lfs_mount(&lfs, &lfs_cfg);
  }
  
  if (fs_err != 0) {
    // Database init fail !!! Discard Database, Use default settings
    discardNVM = 1;
    printf("[NVM/ERR] Flash DataBase Init Fail!\n");
  }
  
  // Read Configs from database
  if(!discardNVM) {
    if(lfs_file_open(&lfs, &file, "bootCount", LFS_O_RDWR | LFS_O_CREAT) == 0) {
      lfs_file_read(&lfs, &file, &bootCount, sizeof(bootCount));
      printf("[NVM/INFO] BootCount %d -> %d\n", bootCount, bootCount+1);
      bootCount += 1;
      lfs_file_rewind(&lfs, &file);
      lfs_file_write(&lfs, &file, &bootCount, sizeof(bootCount));
      lfs_file_close(&lfs, &file);
    }
    
    int needUpdate = 0;
    
    if(lfs_file_open(&lfs, &file, "cfgDevice", LFS_O_RDWR) != 0) {
      printf("[NVM/ERR] Failed to open \"cfgDevice\" file.\n");
      printf("[NVM/WARN] Config version not match! Using default configs\n");
      needUpdate = 1;
    } else {
      lfs_file_read(&lfs, &file, buffer_u32, sizeof(buffer_u32));
      lfs_file_close(&lfs, &file);
      printf("[NVM/INFO] Config version: %d vs %d\n", buffer_u32[0], sDevice.sInfo.pid[0]);
      if(sDevice.sInfo.pid[0] != buffer_u32[0]) {
        printf("[NVM/WARN] Config version not match! Using default configs\n");
        needUpdate = 1;
      }
    }
    
    // Press LENC @Startup to force init FDB
    if(gpio_input_bit_get(GPIOA, GPIO_PIN_0) == 0) {
      printf("[NVM/WARN] User force to use default configs!\n");
      needUpdate = 1;
    }
    
    if(needUpdate) { // Write Configs
      
      LCD_StructInit(true);
      TunerStructInit(&sTuner, true);
      initBasicControl(&sAudioBasic, true);
      initTone(&sAudioTone, true);
      initGraphicEQ(&sAudioEQ, true);
      initKeyFuncPara(&sAudioKeyFunc);
      sDevice.sTime.year = 2024;
      sDevice.sTime.month = 7;
      sDevice.sTime.day = 23;
      sDevice.sTime.hour = 0;
      sDevice.sTime.minute = 0;
      sDevice.sTime.second = 0;
      sDevice.sTime.timestamp = 0;
      saveSettings(CFG_ALL);
      bFlagSync = true;
    } else { // Read Configs
      readSettings(CFG_ALL);
      readChannels(BAND_FM);
      readChannels(BAND_LW);
      readChannels(BAND_MW);
      readChannels(BAND_SW);
      readBasicPara();
    }
  } else {
    LCD_StructInit(true);
    TunerStructInit(&sTuner, true);
    initBasicControl(&sAudioBasic, true);
    initTone(&sAudioTone, true);
    initGraphicEQ(&sAudioEQ, true);
    initKeyFuncPara(&sAudioKeyFunc);
    sDevice.sTime.year = 2024;
    sDevice.sTime.month = 7;
    sDevice.sTime.day = 23;
    sDevice.sTime.hour = 0;
    sDevice.sTime.minute = 0;
    sDevice.sTime.second = 0;
    sDevice.sTime.timestamp = 0;
  }
  
  delay_ms(5);
  SwapEncoder();
  
  // lcd config
  lcd_dma_init();
  LCD_StructInit(false);
  LCD_Init();
  
  if(sDisplay.backTime == 0)
    DAC_OutVal(BLSIG_CH, sDisplay.brightness);
  
  I2C_Init();
  TunerStructInit(&sTuner, false);
  TunerInit(sDevice.nAudioSampleRate);
  
  // special func
  if(sTuner.Config.bFMiPD == true || sTuner.Config.nFMANTsel == 1)
    gpio_bit_set(GPIOC,GPIO_PIN_11);
  
  // audio config
  initBasicControl(&sAudioBasic, false);
  setDCFilter(sAudioBasic.dcBlock);
  setMainVol(sAudioBasic.mainVol);
  setBalance('L', sAudioBasic.balance[0]);
  setBalance('R', sAudioBasic.balance[1]);
  sTuner.Audio.index = 0;
  SetVolume(sTuner.Audio.nVolume[sTuner.Audio.index]);
  sTuner.Audio.index = 1;
  SetVolume(sTuner.Audio.nVolume[sTuner.Audio.index]);
  
  initSignalScaler();
  
  initTone(&sAudioTone, false);
  initGraphicEQ(&sAudioEQ, false);
  
  if(sTuner.Config.bDemoMode == true)
  {
    sAudioKeyFunc.OnOffAUB = true;
    initUltraBass(sAudioKeyFunc.OnOffAUB);
    setUltraBassGain(sAudioKeyFunc.AUBGain);
  }
  
  // Visual Effects
  struct graphicSA sAudioGSA;
  initGraphicSApara(&sAudioGSA);
  initGraphicSA(sAudioGSA);
  
  struct quasiPD sAudioQPD;
  initQPDpara(&sAudioQPD);
  initQPD(sAudioQPD);
  
  RDS_Init(&sRDSData);
  
  nowDET = gpio_input_bit_get(GPIOA,GPIO_PIN_7);
  ApplyAudioOutputByDetect(nowDET);
  SetCoaxOutput(sDevice.bCoaxEnable);
  SetHostI2S0Output(sDevice.bI2SOutEnable);
  lastDET = nowDET;
  
  SetFMStereo(sTuner.Config.nFMST);
  SetFMStereoImprovement(sTuner.Config.bFMSI);
  
  SetMute(sTuner.Audio.bMuted);
  
  UI_Main(true);
  
  timer_enable(TIMER5);
  timer_enable(TIMER6);
  
  while(1)
  {
    
    // 左编码器旋转
    if(lcode != 0)
    {
      if(bFilterSel == true)
        AdjustFilter(lcode);
      else
        AdjustFreq(lcode);
      lcode = 0;
    }
    
    // 目录键按下
    if(keyValue[KEY_MENU] != 0)
    {
      if(keyValue[KEY_MENU] == KEY_PRESS)
      {
        flushKey();
        MenuMain();
      }
      else
      {
        // shut down
      }
      keyValue[KEY_MENU] = 0;
    }
    
    // 上键按下
    if(keyValue[KEY_UP] != 0)
    {
      if(keyValue[KEY_UP] == KEY_PRESS)
      {
        GoChannel(1);
      }
      else
      {
        SearchCH(1);
      }
      keyValue[KEY_UP] = 0;
    }
    
    // 下键按下
    if(keyValue[KEY_DOWN] != 0)
    {
      if(keyValue[KEY_DOWN] == KEY_PRESS)
      {
        GoChannel(-1);
      }
      else
      {
        SearchCH(-1);
      }
      keyValue[KEY_DOWN] = 0;
    }
    
    // 确认键按下
    if(keyValue[KEY_OK] != 0)
    {
      if(keyValue[KEY_OK] == KEY_PRESS)
      {
        bFilterSel = !bFilterSel;
      }
      else
      {
        AddChannel();
      }
      keyValue[KEY_OK] = 0;
    }
    
    // 左编码器按下
    if(keyValue[KEY_LENC] != 0)
    {
      if(keyValue[KEY_LENC] == KEY_PRESS)
      {
        sTuner.Radio.nFreqStep[sTuner.Radio.nBandMode]++;
        if(sTuner.Radio.nFreqStep[sTuner.Radio.nBandMode] == nBandStepNum[sTuner.Radio.nBandMode])
          sTuner.Radio.nFreqStep[sTuner.Radio.nBandMode] = 0;
      }
      else
      {
        RDS_Refresh();
        if(sTuner.Radio.nBandMode == BAND_SW)
          SwitchBand(BAND_FM);
        else
          SwitchBand(sTuner.Radio.nBandMode+1);
      }
      keyValue[KEY_LENC] = 0;
    }
    
    VolumeHandler();
    
    /***************************/
    
    if(bFlagGSA == true && !sDisplay.emiFree)
    {
      bFlagGSA = 0;
      Get_REG(0x1A, (uint8_t *)nGsaVal+1, 9);
      nGsaVal[0] = 1;
      nQPeakDet = getQPDAverPeak();
    }
    if(bFlagRFS == true)
    {
      bFlagRFS = 0;
      GetStatus();
    }
    if(bFlagRDS == true)
    {
      bFlagRDS = 0;
      GetRDS(&sRDSBuffer);
    }
    if(bFlagSync == true) {
      bFlagSync = 0;
      saveBasicPara();
    }
    if(bFlagReBoot == true)
    {
      bFlagReBoot = false;
      if(sDevice.bSoftReboot == true)
      {
        for(int8_t i = sAudioBasic.mainVol; i > -66; i--)
        {
          setMainVol(i);
          delay_ms(20);
        }
        setMute(ADSP_MUTE_MAIN, 1);
        delay_ms(10);
        gpio_bit_reset(GPIOC, GPIO_PIN_4);
        gpio_bit_reset(GPIOA, GPIO_PIN_6);
      }
      
      TunerInit(sDevice.nAudioSampleRate);
      
      setDCFilter(sAudioBasic.dcBlock);
      setMainVol(sAudioBasic.mainVol);
      setBalance('L', sAudioBasic.balance[0]);
      setBalance('R', sAudioBasic.balance[1]);
      
      sTuner.Audio.index = 0;
      SetVolume(sTuner.Audio.nVolume[sTuner.Audio.index]);
      sTuner.Audio.index = 1;
      SetVolume(sTuner.Audio.nVolume[sTuner.Audio.index]);
      nowDET = gpio_input_bit_get(GPIOA,GPIO_PIN_7);
      ApplyAudioOutputByDetect(nowDET);
      SetCoaxOutput(sDevice.bCoaxEnable);
	    SetHostI2S0Output(sDevice.bI2SOutEnable);
      
      lastDET = nowDET;

      SetFMStereo(sTuner.Config.nFMST);
      SetFMStereoImprovement(sTuner.Config.bFMSI);
      
      initSignalScaler();

      initTone(&sAudioTone, false);
      initGraphicEQ(&sAudioEQ, false);
      
      if(sTuner.Config.bDemoMode == true)
      {
        sAudioKeyFunc.OnOffAUB = true;
        initUltraBass(sAudioKeyFunc.OnOffAUB);
        setUltraBassGain(sAudioKeyFunc.AUBGain);
      }
      
      initGraphicSApara(&sAudioGSA);
      initGraphicSA(sAudioGSA);

      initQPDpara(&sAudioQPD);
      initQPD(sAudioQPD);
      
      SetMute(sTuner.Audio.bMuted);
      
      RDS_Init(&sRDSData);
      
      nRebootTimer = 10500;
      
    }
    
    UI_Main(false);
  }
}
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

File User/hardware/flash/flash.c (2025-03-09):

#include "flash.h"
#include "systick.h"

uint8_t flash_readWriteByte(uint8_t TxData)
{
  while(RESET == spi_i2s_flag_get(SPI2, SPI_FLAG_TBE));        //等待发送区空  
	spi_i2s_data_transmit(SPI2, TxData);                         //通过外设SPIx发送一个byte  数据
  while(RESET == spi_i2s_flag_get(SPI2, SPI_FLAG_RBNE));       //等待接收完一个byte  
	return spi_i2s_data_receive(SPI2);                           //返回通过SPIx最近接收的数据	
}


/**
 * @brief  读取FLASH的状态寄存器
       BIT  7   6   5   4    3    2    1     0
					 SPR  RV  TB  BP2  BP1  BP0  WEL  BUSY
					 SPR:默认0,状态寄存器保护位,配合WP使用
					 TB,BP2,BP1,BP0:FLASH区域写保护设置
					 WEL:写使能锁定
					 BUSY:忙标记位(1,忙;0,空闲)
					 默认:0x00
 */
uint8_t flash_readStatueReg(void)
{
	uint8_t byte=0;   
	FLASH_CS(0);
	flash_readWriteByte(FLASH_ReadStatusReg);
	byte=flash_readWriteByte(0Xff);
	FLASH_CS(1);
	return byte;   
}

void flash_writeStatueReg(uint8_t sr)
{
	FLASH_CS(0);
	flash_readWriteByte(FLASH_WriteStatusReg);
	flash_readWriteByte(sr);
  FLASH_CS(1);
}

// onoff 1: enable write    0: disable write
void flash_writeEnable(uint8_t onoff)
{
	FLASH_CS(0);
	onoff ? flash_readWriteByte(FLASH_WriteEnable):flash_readWriteByte(FLASH_WriteDisable);
	FLASH_CS(1);
}

// state 1: power on    0: power off
void flash_power(uint8_t state)
{
	FLASH_CS(0);
	state ? flash_readWriteByte(FLASH_ReleasePowerDown):flash_readWriteByte(FLASH_PowerDown);
	FLASH_CS(1);
	delay_us(100);
}

void flash_waitBusy(uint8_t time)
{
	uint8_t temp;
	while(1)
	{
		if(time != 0)
			delay_ms(time);
		temp = (flash_readStatueReg()&0x01);
		if(temp == 0)
			break;
		delay_us(10);
	}
}

uint16_t flash_readID(void)
{
	uint16_t temp = 0;
	FLASH_CS(0);
	flash_readWriteByte(FLASH_ManufactDeviceID);
	flash_readWriteByte(0x00);
	flash_readWriteByte(0x00);
	flash_readWriteByte(0x00);
	temp |= flash_readWriteByte(0xff) << 8;
	temp |= flash_readWriteByte(0xff);
	FLASH_CS(1);
	return temp;
}

void flash_read(uint32_t addr, uint8_t* buffer, uint32_t numRx)
{
	uint32_t i;
	flash_waitBusy(0);
	FLASH_CS(0);
	flash_readWriteByte(FLASH_ReadData);
	flash_readWriteByte((uint8_t)(addr >> 16));
	flash_readWriteByte((uint8_t)(addr >> 8));
	flash_readWriteByte((uint8_t)(addr));
	for(i=0;i<numRx;i++)
	{
		buffer[i] = flash_readWriteByte(0xff);
	}
	FLASH_CS(1);
}

// numTx <= 256
void flash_program_page(uint32_t addr, uint8_t* data, uint16_t numTx)
{
	uint16_t i;
	flash_waitBusy(0);
	flash_writeEnable(1);
	FLASH_CS(0);
	flash_readWriteByte(FLASH_PageProgram);
	flash_readWriteByte((uint8_t)(addr >> 16));
	flash_readWriteByte((uint8_t)(addr >> 8));
	flash_readWriteByte((uint8_t)(addr));
	for(i=0;i<numTx;i++)
	{
		flash_readWriteByte(data[i]);
	}
	FLASH_CS(1);
}


void flash_program(uint32_t addr, uint8_t* data, uint32_t numTx)
{
	uint8_t* data_ptr = data;
	uint32_t nowaddr = addr;
	uint32_t numByte = numTx;
	uint16_t pageremain = 256-nowaddr%256;
	
	if(numByte<=pageremain)
		pageremain = numByte;
	
	while(1)
	{
		flash_program_page(nowaddr, data_ptr, pageremain);
		if(numByte == pageremain)
			break;
		else
		{
			data_ptr+=pageremain;
			nowaddr+=pageremain;
			numByte-=pageremain;
			if(numByte>256)
				pageremain = 256;
			else
				pageremain = numByte;
		}
	}
	
}

#define BULK_SIZE    4096

int flash_erase_bulk(uint32_t addr, uint32_t size)
{
  uint32_t i = 0;
  uint32_t sAddr = addr;
  int erase_pages = size / BULK_SIZE;
  if( size % BULK_SIZE != 0) {
    erase_pages++;
  }
  
  for(i = 0; i < erase_pages; i++) {
    flash_waitBusy(0);
    flash_writeEnable(1);
    FLASH_CS(0);
    
    flash_readWriteByte(ERASE_SECTOR);
    
    flash_readWriteByte((uint8_t)( (sAddr+BULK_SIZE*i) >> 16));
    flash_readWriteByte((uint8_t)( (sAddr+BULK_SIZE*i) >> 8));
    flash_readWriteByte((uint8_t)( (sAddr+BULK_SIZE*i) ));
    
    FLASH_CS(1);
    flash_waitBusy(15);
  }
  
  return erase_pages;
}

uint8_t flash_erase(uint8_t type, uint16_t index)
{
	uint32_t addr;
	
	flash_waitBusy(0);
	flash_writeEnable(1);
	FLASH_CS(0);
	flash_readWriteByte(type);
	if(type != ERASE_CHIP)
	{
		switch(type)
		{
			case ERASE_PAGE:{
				if(index >= NUM_PAGE)
					return 1;
				addr=index<<8; // *256(2^8)
			};break;
			
			case ERASE_SECTOR:{
				if(index >= NUM_SECTOR)
					return 1;
				addr=index<<12; // *4096(2^12)
			};break;
			
			case ERASE_BLOCK32K:{
				if(index >= NUM_BLOCK32K)
					return 1;
				addr=index<<15; // *4096*8(2^15)
			};break;
			
			case ERASE_BLOCK64K:{
				if(index >= NUM_BLOCK64K)
					return 1;
				addr=index<<16; // *4096*16(2^16)
			};break;
		}
		flash_readWriteByte((uint8_t)(addr >> 16));
		flash_readWriteByte((uint8_t)(addr >> 8));
		flash_readWriteByte((uint8_t)(addr));
	}
	FLASH_CS(1);
	flash_waitBusy(15);
	return 0;
}


uint8_t local_buffer[4096];
void flash_write(uint32_t addr, uint8_t* data, uint32_t numTx)
{
	uint16_t i;
	uint32_t byteleft = numTx;
	uint32_t addrnow = addr;
	
	uint16_t secleft;
	uint32_t secaddr;
	uint32_t secofst;
	
	uint8_t* ptr = data;
	
	while(byteleft)
	{
		secaddr = addrnow/4096;
		secofst = addrnow%4096;
		
		(byteleft < 4096-secofst)? (secleft = byteleft):(secleft = 4096-secofst);
		
		flash_read(secaddr*4096, local_buffer, 4096);
		for(i=0;i<secleft;i++)
		{
			local_buffer[secofst+i] = ptr[i];
		}
		// erase
		flash_erase(ERASE_SECTOR, secaddr);
		// program
		flash_program(secaddr*4096, local_buffer, 4096);
		
		byteleft-=secleft;
		addrnow +=secleft;
		ptr += secleft;
	}
}

void flash_spi_init(void)
{
	rcu_periph_clock_enable(RCU_GPIOB);
	rcu_periph_clock_enable(RCU_GPIOD);
	rcu_periph_clock_enable(RCU_AF);
	rcu_periph_clock_enable(RCU_SPI2);
	
	delay_us(10);
	
	//PD2 -> FLASH_CS
	GPIO_BOP(GPIOD) = GPIO_PIN_2;
	gpio_init(GPIOD, GPIO_MODE_OUT_PP, GPIO_OSPEED_50MHZ, GPIO_PIN_2);
	//PB3,5 -> SPI2_SCK,MOSI
	gpio_init(GPIOB, GPIO_MODE_AF_PP, GPIO_OSPEED_50MHZ, GPIO_PIN_3 | GPIO_PIN_5);
	//PB4 -> SPI2_MISO
	gpio_init(GPIOB, GPIO_MODE_IN_FLOATING, GPIO_OSPEED_50MHZ, GPIO_PIN_4);
	
	
	spi_parameter_struct sspi;
	/* deinitilize SPI and the parameters */
	spi_struct_para_init(&sspi);
	
	spi_i2s_deinit(SPI2);
	/* SPI2 parameter config */
	sspi.trans_mode           = SPI_TRANSMODE_FULLDUPLEX;
	sspi.device_mode          = SPI_MASTER;
	sspi.frame_size           = SPI_FRAMESIZE_8BIT;
	sspi.clock_polarity_phase = SPI_CK_PL_HIGH_PH_2EDGE;
	sspi.nss                  = SPI_NSS_SOFT;
	sspi.prescale             = SPI_PSC_2;  //F = 60MHz(APB1) / 2(PSC) = 30MHz (Max = 33MHz)
	sspi.endian               = SPI_ENDIAN_MSB;
	spi_init(SPI2, &sspi);
	
	spi_nss_output_disable(SPI2);
	
	spi_enable(SPI2);
}

uint16_t flash_init(void)
{
	flash_spi_init();
	
	FLASH_CS(1);
	
	flash_power(1);
	
	return flash_readID();
}

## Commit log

2024-06-28 初次同步
2024-07-26 rebuild lcd driver
2025-02-25 update: 新增主界面低EMI模式，RDS信息展示
2025-03-09 update: 移植FlashDB
2026-06-05 fix: some problems introduced by AI
    [SAF775X.c, main.c]
2026-06-28 delete: 删除非必要同步文件
2026-06-28 add: 硬件相关文档
    [BOM_MBR GD32_20230816.xlsx, SAF775X Receiver Bottom.3dm, SAF775X Receiver Bottom.stl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]
2026-08-29 update: 支持编码器互换
2026-09-01 merge: 7751 采样率切换
